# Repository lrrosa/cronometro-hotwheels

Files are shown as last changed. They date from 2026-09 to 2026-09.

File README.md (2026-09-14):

# Cronômetro Hot Wheels — 6 raias

Cronômetro de largada e chegada para pista de carrinhos com seis raias. Um
microswitch na porta de largada marca o `t0`, um sensor infravermelho
**TCRT5000** no fim de cada raia marca a chegada, e seis displays **TM1637**
mostram a colocação (1 a 6) e depois o tempo de cada carro.

Diagrama de fiação — versão Arduino

## Duas versões, mesmo comportamento

| | [`cronometro-rasp-pico`](cronometro-rasp-pico/) | [`cronometro-arduino`](cronometro-arduino/) |
| --- | --- | --- |
| Placa | Raspberry Pi Pico / RP2040 (inclusive a roxa) | Arduino UNO / Nano |
| Linguagem | C, Pico SDK 1.5.1 | C++, Arduino (um `.ino` só) |
| Tensão | 3,3 V | 5 V |
| Simulador | Wokwi no VS Code | Wokwi no VS Code **ou** wokwi.com, sem instalar nada |
| Fiação | [SVG](cronometro-rasp-pico/docs/fiacao-pico.svg) | [SVG](cronometro-arduino/docs/fiacao-arduino.svg) |
| Esquema KiCad 10 | [projeto](cronometro-rasp-pico/kicad/) · [PDF](cronometro-rasp-pico/docs/esquema-kicad.pdf) | [projeto](cronometro-arduino/kicad/) · [PDF](cronometro-arduino/docs/esquema-kicad.pdf) |
| Teto de raias | 9 | 6 |

A máquina de estados, os tempos, os sons e o formato do placar são os mesmos
nas duas. O que a plataforma obrigou a mudar está em
[diferencas-rp2040.md](cronometro-arduino/docs/diferencas-rp2040.md).

**Para só ver funcionando:** a versão Arduino no wokwi.com — dois arquivos
colados e play.

## Documentação que vale para as duas

- [Lista de material e cuidados elétricos](cronometro-rasp-pico/docs/bom.md) —
  por que o sensor é infravermelho e não LDR (a disputa mais apertada do vídeo
  de referência foi decidida por 17 ms), como montar o TCRT5000, e a conta de
  consumo.
- [Notas do projeto](cronometro-rasp-pico/NOTAS.md) — decisões, medidas e
  armadilhas, para não refazer o raciocínio depois.

## Desenhos gerados

Os diagramas de fiação e os esquemas do KiCad saem de scripts; não edite à
mão. Da raiz do repositório:

```bash
python tools/gen_esquema_svg.py
```

```bash
python tools/gen_kicad_sch.py --verificar
```

O primeiro confere, segmento a segmento, que nenhum fio de sinal cruza outro.
O segundo precisa do KiCad 10 instalado: roda o ERC e exporta o netlist pelo
próprio KiCad, conferindo rede por rede contra a pinagem do firmware — o ERC
sozinho só prova regra elétrica; é o netlist que prova que cada fio chega no
pino certo. Os dois saem com erro se a conferência falhar.

## Pacotes de release

Cada [release](https://github.com/lrrosa/cronometro-hotwheels/releases) traz
um zip por placa, com o que interessa a quem vai montar: `LEIA-ME.txt` com a
montagem em ordem, fiação em SVG e PNG, lista de material, pinagem, esquema
em PDF e o projeto KiCad, o simulador já com o binário, o código e as
licenças. O do Pico traz também quatro `.uf2` prontos — ponto decimal ×
polaridade do sensor —, para gravar sem instalar o SDK.

Os zips saem de um script, a partir de um commit limpo:

```bash
python tools/empacotar_release.py 1.0.0
```

Ele compila as quatro variantes do Pico e o sketch do Arduino, renderiza os
diagramas em PNG pelo Edge headless, troca os links que apontariam para fora
do pacote por URLs do GitHub fixadas na tag e confere que todo link relativo
que sobrou existe dentro do zip.

Precisa do Pico SDK 1.5.1, do `arduino-cli` com o core `arduino:avr` e do
Edge. No Windows, rode com um Python que **não** seja o da Microsoft Store:
os processos filhos dele não enxergam o core instalado do `arduino-cli`. O
Python que vem com o Pico SDK serve.

## Licença

Projeto com **licença dupla**, a mesma do
[RetroSC Pong](https://github.com/lrrosa/retrosc-pong) — ver [`NOTICE`](NOTICE)
para o detalhamento por arquivo:

- **Software** (firmwares, geradores em `tools/`, circuito do simulador) —
  **[GPL-3.0-or-later](LICENSE)** (`SPDX-License-Identifier: GPL-3.0-or-later`).
- **Hardware** (projetos e esquemas do KiCad, diagramas de fiação, `bom.md`,
  `pinout.md`) — **[CERN-OHL-S-2.0](LICENSE-HARDWARE.txt)**
  (`SPDX-License-Identifier: CERN-OHL-S-2.0`), a variante *Strongly
  Reciprocal* da CERN Open Hardware Licence.

As duas são **recíprocas** (copyleft): trabalhos derivados devem manter a mesma
licença e disponibilizar as fontes correspondentes — código, no caso do
software; arquivos de projeto, no caso do hardware.

Copyright (C) 2026 Leonardo Roman da Rosa.

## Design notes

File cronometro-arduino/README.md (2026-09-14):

# Cronômetro Hot Wheels — 6 pistas (Arduino UNO / Nano)

Mesmo projeto da pasta [`cronometro-rasp-pico`](../cronometro-rasp-pico/),
portado para o **ATmega328P**. Comportamento idêntico; o que muda é a
plataforma, e isso está registrado em
[docs/diferencas-rp2040.md](docs/diferencas-rp2040.md).

- Um **microswitch** na porta que solta os carrinhos marca o `t0`.
- Um **sensor infravermelho TCRT5000** no fim de cada raia marca a chegada,
  pela saída digital D0.
- Seis **displays TM1637** mostram a **colocação** (1 a 6) assim que cada
  carro cruza, e depois o **tempo** (`3721` = 3,721 s).

O código é **um arquivo só** de propósito: assim cabe num único "colar" no
wokwi.com, que compila na nuvem e não exige nada instalado.

## Desenhos

- [**Diagrama de fiação**](docs/fiacao-arduino.svg) — módulos, barramentos e cada fio com o
  nome do pino. É o que se segue na montagem.
- [**Esquema KiCad 10**](kicad/) — abra `kicad/cronometro-arduino.kicad_pro`; também
  exportado em [SVG](docs/esquema-kicad.svg) e [PDF](docs/esquema-kicad.pdf).

Diagrama de fiação

Os dois são gerados pelos scripts em `tools/`, na raiz do repositório — ver o
README de lá.

## Rodar no simulador — sem instalar nada

1. Abra **[wokwi.com](https://wokwi.com)** → *New Project* → **Arduino Uno**.
2. Na aba `sketch.ino`, apague tudo e cole o conteúdo de
   [cronometro-arduino.ino](cronometro-arduino.ino).
3. Na aba `diagram.json`, apague tudo e cole o conteúdo de
   [diagram.json](diagram.json).
4. Play. Passo a passo do que fazer dentro do simulador em
   [docs/como-simular.md](docs/como-simular.md).

> Vantagem deste caminho: não precisa compilar nada. Mas o **simulador
> local do VS Code também funciona** — ver
> [docs/como-simular.md](docs/como-simular.md).

## Compilar e gravar na placa

Pelo **Arduino IDE**: abra `cronometro-arduino.ino` — a pasta tem que se chamar
`cronometro-arduino`, como o sketch —, escolha a placa (*Arduino Uno* ou
*Arduino Nano*) e a porta, e clique em Upload.

Pelo **arduino-cli**, de dentro da pasta do sketch:

```bash
arduino-cli core install arduino:avr
arduino-cli compile -b arduino:avr:uno --warnings all --output-dir build .
arduino-cli upload -b arduino:avr:uno -p COM3 .
```

Troque `COM3` pela porta que aparece em `arduino-cli board list`. Para Nano,
use `arduino:avr:nano` (clone com bootloader antigo:
`arduino:avr:nano:cpu=atmega328old`). Com o `--output-dir build`, o
[wokwi.toml](wokwi.toml) também passa a funcionar na extensão do VS Code.

**Ocupação medida** (compilado, não estimado): programa **9252 bytes**, 28 %
dos 32 KB do UNO (29 % dos 30 KB do Nano, que tem bootloader maior);
variáveis globais **465 bytes**, 22 % da RAM. Cabe com muita folga.

## Ligações

| Função | Pino | Observação |
| --- | --- | --- |
| Sensores TCRT5000 (D0) das raias 1 a 6 | **A0 a A5** | **a ordem é obrigatória** — ver abaixo |
| Microswitch da porta | D2 | precisa ser D2 ou D3 (interrupção externa) |
| TM1637 **CLK** (comum aos seis) | D3 | |
| TM1637 DIO das raias 1 a 6 | D4, D5, D6, D7, D8, D9 | |
| Buzzer passivo (opcional) | D10 | |
| Botão TESTE / rearma (opcional) | D11 | |
| Log serial | D0/D1 (USB), 115200 | |
| Alimentação | 5 V e GND | displays e sensores |

Sobram livres só **D12 e D13**. Tabela completa, com as duas placas, em
[docs/pinout.md](docs/pinout.md).

**Por que os sensores têm que ser A0..A5, nessa ordem:** o ATmega328P só
tem **duas** interrupções externas de verdade (D2 e D3) — não dão para seis
pistas. A saída é a interrupção de *mudança de pino*: A0–A5 são a PORTC
inteira, e as seis cabem numa única `PCINT1`. A rotina lê a porta de uma vez
e descobre quem mudou pelo XOR com a leitura anterior. Isso amarra a raia
*i* ao pino A*i* — por isso não existe tabela de pinos para elas, ao
contrário dos displays.

**Tudo em 5 V**, e aqui isso é uma vantagem: o TM1637 trabalha na tensão
nativa dele (fica mais brilhante) e o DIO em 5 V não é problema nenhum,
porque o 328P é uma peça de 5 V. Na versão RP2040 isso era a armadilha mais
perigosa do projeto.

## Como se comporta

| Estado | Displays | Sai daqui quando |
| --- | --- | --- |
| **Armado** | `----` fixo (ou piscando, se a porta estiver aberta) | a porta abre |
| **Correndo** | cronômetro correndo; quem chega troca para a colocação | todos chegam, ou 8 s depois do 1º, ou 15 s no total |
| **Resultado** | alterna colocação (4,5 s) ↔ tempo (7 s) | a porta fecha (ou o botão TESTE) |

- Carro que não passa pelo sensor aparece como `dnF` e `----`.
- **Fechar a porta rearma** — não precisa de botão para a próxima prova.
- Ao ligar, cada display acende **tudo** (segmentos e pontos) e depois o
  número da própria raia:
  se um ficar apagado ou mostrar o número de outra raia, o erro está no DIO
  dele, não no código. O primeiro quadro também revela se o módulo liga um
  ponto por dígito — ver `DISPLAY_PONTO_DECIMAL`.
- **Corrida demo** (para ver o painel sem carrinho): segure o botão TESTE
  por 1 s, ou segure um carrinho sobre o sensor da raia 1 por 2 s com a prova armada.

## Ajustes

Tudo no bloco **CONFIGURAÇÃO** no topo de
[cronometro-arduino.ino](cronometro-arduino.ino):

| Constante | Para quê |
| --- | --- |
| `SENSOR_NIVEL_CARRO` | `0` (padrão) é o TCRT5000: D0 cai com o carro. `1` se o seu lote for invertido |
| `LARGADA_NIVEL_ABERTA` | idem, para o microswitch (contato NA ou NF) |
| `DISPLAY_PONTO_DECIMAL` | `0` (padrão) para o módulo de dois-pontos; `1` para o de ponto por dígito |
| `TM1637_BRILHO` | 0 a 7 — mexe direto no consumo |
| `TEMPO_MIN_MS` | piso abaixo do qual a chegada é considerada ruído |
| `ESPERA_APOS_1o_MS` | quanto esperar os retardatários depois do 1º |
| `USAR_BUZZER` / `USAR_BOTAO` | `0` libera o D10 / D11 |

`N_PISTAS` **não** é ajustável para cima aqui: seis é o teto do 328P, porque
a PORTC só expõe seis pinos no conector. Ver
[docs/diferencas-rp2040.md](docs/diferencas-rp2040.md).

## Material

O mesmo da versão RP2040 —
[lista completa e os avisos elétricos](../cronometro-rasp-pico/docs/bom.md),
inclusive por que o sensor é o TCRT5000 e não LDR, e como montá-lo.

Por causa dos 5 V, aqui **displays e sensores vão direto no 5 V** da placa, e
não é preciso o regulador 3,3 V separado que a versão RP2040 recomenda. A
conta de consumo continua valendo: por USB passa, pelo conector DC de 12 V o
regulador do UNO esquenta.

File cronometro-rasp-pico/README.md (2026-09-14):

# Cronômetro Hot Wheels — 6 pistas (RP2040)

Cronômetro de largada e chegada para pista de carrinhos com 6 raias, no
Raspberry Pi Pico / RP2040 (testado na compilação com o **Pico SDK 1.5.1**,
o mesmo do projeto Pong).

- Um **microswitch** na porta que solta os carrinhos marca o `t0`.
- Um **sensor infravermelho TCRT5000** no fim de cada raia marca a chegada daquele
  carro, pela saída digital D0. A escolha do infravermelho em vez
  do LDR está justificada com números em [docs/bom.md](docs/bom.md) — em
  resumo: a prova de referência teve colocações decididas por 17 ms, e a
  dispersão de um LDR para outro é dessa mesma ordem.
- Seis **displays TM1637** mostram a **colocação** (1 a 6) assim que cada
  carro cruza, e depois o **tempo em segundos** (`3721` = 3,721 s; se os seus
  módulos tiverem ponto por dígito, `DISPLAY_PONTO_DECIMAL = 1` mostra
  `3.721`, como no vídeo original).

Vem com um **simulador Wokwi** pronto (`diagram.json` + `wokwi.toml`) — dá
para rodar a corrida inteira no VS Code antes de comprar ou soldar nada.
Passo a passo em [docs/como-simular.md](docs/como-simular.md).

> Existe a **mesma coisa para Arduino UNO/Nano** em
> [`../cronometro-arduino`](../cronometro-arduino/), num arquivo `.ino` só,
> que roda no wokwi.com sem instalar nada. O que muda entre as duas está em
> [diferencas-rp2040.md](../cronometro-arduino/docs/diferencas-rp2040.md).

## Desenhos

- [**Diagrama de fiação**](docs/fiacao-pico.svg) — módulos, barramentos e cada fio com o
  nome do pino. É o que se segue na montagem.
- [**Esquema KiCad 10**](kicad/) — abra `kicad/cronometro-rasp-pico.kicad_pro`; também
  exportado em [SVG](docs/esquema-kicad.svg) e [PDF](docs/esquema-kicad.pdf).

Diagrama de fiação

Os dois são gerados pelos scripts em `tools/`, na raiz do repositório — ver o
README de lá.

## Como se comporta

| Estado | Displays | Sai daqui quando |
| --- | --- | --- |
| **Armado** | `----` fixo (ou piscando, se a porta estiver aberta) | a porta abre |
| **Correndo** | cronômetro correndo em cada raia; quem chega troca para a colocação | todos chegam, ou 8 s depois do 1º, ou 15 s no total |
| **Resultado** | alterna colocação (4,5 s) ↔ tempo (7 s) | a porta fecha (ou o botão TESTE) |

- Carro que não cruza o sensor aparece como `dnF` na colocação e `----` no tempo.
- Com a porta fechada, o placar fica na tela por dois ciclos inteiros
  (`RESULTADO_MIN_MS`, 23 s) antes de rearmar sozinho; com a porta aberta,
  fica até alguém fechá-la.
- **Fechar a porta rearma** — não precisa de botão para a próxima prova.
- Ao ligar, cada display acende **tudo** (segmentos e pontos) e depois o
  número da própria raia:
  se um ficar apagado ou mostrar o número de outra raia, o erro está no
  DIO dele, não no firmware. O primeiro quadro também revela se o módulo liga
  um ponto por dígito — ver `DISPLAY_PONTO_DECIMAL`.

### Corrida demo

Para ver o painel funcionando sem carrinho nenhum (no simulador ou na
bancada), há dois atalhos, e as chegadas simuladas entram pelo **mesmo
caminho** das reais:

- segurar o botão **TESTE** por 1 s (tecla `D` no Wokwi);
- ou **segurar um carrinho sobre o sensor da raia 1** por 2 s com a prova
  armada — funciona sem botão nenhum, e de quebra confere a polaridade.

## Compilar

```powershell
& "C:\Program Files\Raspberry Pi\Pico SDK v1.5.1\pico-env.ps1"
cmake -G Ninja -B build
& "C:\Program Files\Raspberry Pi\Pico SDK v1.5.1\ninja\ninja.exe" -C build
```

Saída: `build/cronometro-rasp-pico.uf2`. Para gravar, segure BOOTSEL, ligue
o USB e copie o `.uf2` para a unidade `RPI-RP2`.

`DISPLAY_PONTO_DECIMAL` e `SENSOR_NIVEL_CARRO` também podem ser escolhidos na
configuração do CMake, sem editar o `config.h` — é assim que o release gera
os quatro `.uf2` prontos:

```powershell
cmake -G Ninja -B build -DPONTO_DECIMAL=1 -DSENSOR_NIVEL=1
```

As opções ficam no cache do CMake. Para voltar ao que diz o `config.h`, passe
as duas vazias (`-DPONTO_DECIMAL= -DSENSOR_NIVEL=`) ou apague a pasta `build`.

## Ligações

Resumo — a tabela completa, com a posição física do furo em cada módulo
(Pico oficial e RP2040 roxa), está em [docs/pinout.md](docs/pinout.md).

| Função | GPIO |
| --- | --- |
| Sensores TCRT5000 (D0) das raias 1 a 6 | GP2, GP3, GP4, GP5, GP6, GP7 |
| Microswitch da porta | GP8 |
| TM1637 **CLK** (comum aos seis) | GP9 |
| TM1637 DIO das raias 1 a 6 | GP10, GP11, GP12, GP13, GP14, GP15 |
| Buzzer passivo (opcional) | GP16 |
| Botão TESTE / rearma (opcional) | GP21 |
| Log serial | USB, e UART0 em GP0/GP1 |

> **Tudo em 3,3 V — displays e sensores.** O TM1637 e o TCRT5000 têm
> pull-up para o VCC do próprio módulo: alimentados em 5 V, põem 5 V num
> GPIO do RP2040, que **não** é tolerante a 5 V. Ver [docs/bom.md](docs/bom.md),
> que também explica por que vale usar um regulador 3,3 V separado.

Os seis displays dividem o **mesmo CLK**: o TM1637 não tem endereço, quem
seleciona o chip é a linha DIO. Enquanto se escreve numa raia, os outros
cinco veem o clock mas com o DIO parado em nível alto — sem condição de
START, eles ignoram tudo. São 7 pinos em vez de 12, e trocar para um CLK
por display é só mudar a tabela em `src/config.c`.

## Arquivos

```
src/config.{h,c}    pinos, polaridades e tempos — o que se mexe
src/tm1637.{h,c}    protocolo de dois fios do display
src/display.{h,c}   fonte de 7 segmentos e formatação (tempo, colocação)
src/cronometro.{h,c} máquina de estados da prova
src/som.{h,c}       bips no buzzer (não bloqueantes)
src/main.c          init + laço principal
diagram.json        circuito do simulador Wokwi (gerado, não editado a mão)
tools/gen_diagram.py  gera o diagram.json e confere o roteamento dos fios
wokwi.toml          aponta o Wokwi para o firmware compilado
docs/               pinagem, lista de material, como simular
NOTAS.md            decisões, medidas e armadilhas do projeto
```

## Ajustes que você provavelmente vai querer mexer

Tudo em [src/config.h](src/config.h):

| Constante | Para quê |
| --- | --- |
| `N_PISTAS` | número de raias (mexa junto com as tabelas de `config.c`) |
| `SENSOR_NIVEL_CARRO` | `0` (padrão) é o TCRT5000: D0 cai com o carro. `1` se o seu lote for invertido |
| `LARGADA_NIVEL_ABERTA` | idem, para o microswitch (contato NA ou NF) |
| `DISPLAY_PONTO_DECIMAL` | `1` se o módulo tem ponto por dígito, `0` (padrão) se só tem dois-pontos no meio |
| `TM1637_BRILHO` | 0 a 7 — mexe direto no consumo, ver `docs/bom.md` |
| `TEMPO_MIN_MS` | piso de tempo abaixo do qual a chegada é considerada ruído |
| `ESPERA_APOS_1o_MS` | quanto tempo esperar os retardatários depois do 1º |

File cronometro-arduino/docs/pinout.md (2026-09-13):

# Pinagem — Arduino UNO / Nano (ATmega328P)

Aqui não existe o problema que a versão RP2040 tem com as placas clone: o
nome serigrafado na placa **é** o nome usado no código. `D4` é `D4` no UNO e
no Nano. Por isso esta página não traz tabela de posição física — traz o
mapeamento para as portas do AVR, que é o que importa para entender as
amarrações.

Os pinos ficam no bloco **CONFIGURAÇÃO** no topo de
[../cronometro-arduino.ino](../cronometro-arduino.ino).

## Sinais do projeto

| Função | Pino | Porta AVR | Dir | Observação |
| --- | --- | --- | --- | --- |
| TCRT5000 raia 1 (D0) | **A0** | PC0 | IN | ativo em 0; o pull-up já vem no módulo |
| TCRT5000 raia 2 (D0) | **A1** | PC1 | IN | |
| TCRT5000 raia 3 (D0) | **A2** | PC2 | IN | |
| TCRT5000 raia 4 (D0) | **A3** | PC3 | IN | |
| TCRT5000 raia 5 (D0) | **A4** | PC4 | IN | (é também o SDA do I²C, se um dia precisar) |
| TCRT5000 raia 6 (D0) | **A5** | PC5 | IN | (SCL) |
| Microswitch da porta | **D2** | PD2 | IN | **INT0** — contato para GND, pull-up interno |
| TM1637 **CLK** (comum) | **D3** | PD3 | OUT | vai nos seis displays |
| TM1637 DIO raia 1 | **D4** | PD4 | I/O | dreno aberto emulado |
| TM1637 DIO raia 2 | **D5** | PD5 | I/O | |
| TM1637 DIO raia 3 | **D6** | PD6 | I/O | |
| TM1637 DIO raia 4 | **D7** | PD7 | I/O | |
| TM1637 DIO raia 5 | **D8** | PB0 | I/O | |
| TM1637 DIO raia 6 | **D9** | PB1 | I/O | |
| Buzzer passivo | **D10** | PB2 | OUT | opcional (`USAR_BUZZER`) |
| Botão TESTE / rearma | **D11** | PB3 | IN | opcional (`USAR_BOTAO`) |
| Log serial | D0 / D1 | PD0/PD1 | — | 115200, pelo USB |
| **5 V** | — | — | — | displays e sensores |
| **GND** | — | — | — | massa comum |

Sobram livres **D12 (PB4)** e **D13 (PB5)**. Só.

## As três amarrações que não dá para mexer

1. **Os sensores têm que ser A0–A5, nessa ordem.** O 328P só tem duas
   interrupções externas de verdade (D2 e D3); para seis pistas a saída é a
   interrupção de mudança de pino, e A0–A5 são a PORTC inteira, que cai toda
   numa única `PCINT1`. A rotina lê `PINC` de uma vez. Trocar dois sensores
   de pino troca as raias.
2. **A largada tem que ser D2 ou D3.** São os únicos pinos com interrupção
   externa. D3 já é o CLK dos displays, então sobra D2.
3. **Seis raias é o teto.** A PORTC só expõe seis pinos no conector — PC6 é
   o RESET. O Nano tem A6/A7, mas eles são **só analógicos**: não têm
   registrador de entrada digital nem PCINT, e portanto não servem para
   sensor. Para sete ou mais raias, o caminho é outro micro (o RP2040 da
   pasta vizinha tem folga para nove).

## Armadilhas conhecidas desta pinagem

- **`tone()` usa o Timer2**, e isso desliga o `analogWrite` dos pinos **D3 e
  D11**. Aqui não dá problema porque D3 é saída digital (CLK) e D11 é
  entrada (botão) — nenhum dos dois usa PWM. Mas se um dia alguém quiser um
  LED com brilho variável, não pode ser nesses dois.
- **D10 a D13 são o barramento SPI** (SS, MOSI, MISO, SCK). O projeto usa
  D10 e D11 para buzzer e botão. Se um dia entrar um cartão SD para gravar
  os tempos, mude buzzer e botão para D12/D13 antes de ligar o SPI.
- **D13 tem o LED de bordo**, com resistor para o GND. Não serve como
  entrada com pull-up (o LED puxa o nível para baixo). Se precisar de mais
  uma entrada, use D12.
- **D0/D1 são a serial**. Ligar qualquer coisa neles atrapalha a gravação
  pelo USB e o log dos tempos.

## Cabeamento sugerido

Cada TM1637 precisa de 4 fios e cada TCRT5000 de 3 (VCC, GND e D0 — o A0
do módulo fica solto; não confundir com o **pino** A0 do Arduino, que recebe
o D0 do sensor da raia 1). Em vez de puxar tudo até a placa:

- **5 V e GND** em duas barras percorrendo o painel, com os módulos
  pendurados nelas (é assim que o `diagram.json` e o
  [diagrama de fiação](fiacao-arduino.svg) estão desenhados).
- **CLK** também em cascata, um fio curto de um display para o outro. O
  módulo preto de 0,56" tem header dos dois lados, o que deixa isso trivial.
- Só os **6 DIO** dos displays e os **6 D0** dos sensores voltam
  individualmente à placa.

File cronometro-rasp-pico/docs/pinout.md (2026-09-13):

# Pinagem

Os GPIOs ficam em [../src/config.h](../src/config.h) e
[../src/config.c](../src/config.c). O **firmware é o mesmo** para o Pico
oficial e para a RP2040 roxa — o RP2040 é idêntico, o que muda é em qual
furo da placa cada GPIO aparece.

**Posições físicas** na numeração padrão do Pico: pino 1 no canto do USB,
1–20 descem a coluna esquerda, 21–40 sobem a direita.

## Sinais do projeto

| Função | GPIO | Dir | Pico oficial | RP2040 roxa | Observação |
| --- | --- | --- | --- | --- | --- |
| TCRT5000 raia 1 (D0) | GP2 | IN | 4 | **3** | ativo em 0; o pull-up já vem no módulo |
| TCRT5000 raia 2 (D0) | GP3 | IN | 5 | **4** | |
| TCRT5000 raia 3 (D0) | GP4 | IN | 6 | **5** | |
| TCRT5000 raia 4 (D0) | GP5 | IN | 7 | **7** | |
| TCRT5000 raia 5 (D0) | GP6 | IN | 9 | **8** | |
| TCRT5000 raia 6 (D0) | GP7 | IN | 10 | **9** | |
| Microswitch da porta | GP8 | IN | 11 | **10** | contato para GND, pull-up interno |
| TM1637 **CLK** (comum) | GP9 | OUT | 12 | **11** | vai nos seis displays |
| TM1637 DIO raia 1 | GP10 | I/O | 14 | **12** | dreno aberto emulado |
| TM1637 DIO raia 2 | GP11 | I/O | 15 | **13** | |
| TM1637 DIO raia 3 | GP12 | I/O | 16 | **14** | |
| TM1637 DIO raia 4 | GP13 | I/O | 17 | **16** | |
| TM1637 DIO raia 5 | GP14 | I/O | 19 | **17** | |
| TM1637 DIO raia 6 | GP15 | I/O | 20 | **18** | |
| Buzzer passivo | GP16 | OUT | 21 | **19** | opcional (`USAR_BUZZER`) |
| Botão TESTE / rearma | GP21 | IN | 27 | **24** | opcional (`USAR_BOTAO`) |
| UART0 TX / RX (log) | GP0 / GP1 | — | 1 / 2 | 1 / 2 | opcional; o USB também loga |
| **3,3 V** | — | — | 36 | 36 | displays e sensores (ou regulador separado, ver bom.md) |
| **GND** | — | — | 3, 8, 13, 18, 23, 28, 38 | 6, 15, 35, 38 | massa comum |
| +5 V (não usado) | — | — | 40 (VBUS) | 40 (VBUS) | **não** ligue nos TM1637 |

Sobram livres: GP17 a GP20, GP22, GP26 a GP28 (os três com ADC). Dá para
crescer para 8 ou 9 raias sem reorganizar nada — só estender as tabelas de
`config.c` e `N_PISTAS`.

## Por que estes GPIOs

- **Sensores em GP2–GP7, contíguos.** Facilita conferir o cabo flat e
  permite ler as seis raias num único `gpio_get_all()`, caso um dia se
  queira amostrar por polling em vez de interrupção.
- **GP0/GP1 livres** para a UART0, que é o que o monitor serial do Wokwi lê.
- **GP16 (buzzer)** é canal A do slice 0 do PWM e não disputa nada.
- **Nada em GP23, GP24, GP25 nem GP29.** No Pico oficial esses pinos são do
  regulador, do sensor de VBUS e do LED, e nem aparecem nos furos; na roxa
  aparecem, mas usá-los amarraria o projeto a uma placa só.

## Pinagem completa das duas placas

| Pos | Pico oficial | RP2040 roxa |
| --- | --- | --- |
| 1 | GP0 | GP0 |
| 2 | GP1 | GP1 |
| 3 | GND | **GP2** |
| 4 | **GP2** | **GP3** |
| 5 | **GP3** | **GP4** |
| 6 | **GP4** | GND |
| 7 | **GP5** | **GP5** |
| 8 | GND | **GP6** |
| 9 | **GP6** | **GP7** |
| 10 | **GP7** | **GP8** |
| 11 | **GP8** | **GP9** |
| 12 | **GP9** | **GP10** |
| 13 | GND | **GP11** |
| 14 | **GP10** | **GP12** |
| 15 | **GP11** | GND |
| 16 | **GP12** | **GP13** |
| 17 | **GP13** | **GP14** |
| 18 | GND | **GP15** |
| 19 | **GP14** | **GP16** |
| 20 | **GP15** | GP17 |
| 21 | **GP16** | GP18 |
| 22 | GP17 | GP19 |
| 23 | GND | GP20 |
| 24 | GP18 | **GP21** |
| 25 | GP19 | GP22 |
| 26 | GP20 | GP23 |
| 27 | **GP21** | GP24 |
| 28 | GND | GP25 |
| 29 | GP22 | AGND |
| 30 | RUN | GP26/A0 |
| 31 | GP26/ADC0 | GP27/A1 |
| 32 | GP27/ADC1 | GP28/A2 |
| 33 | AGND | GP29/A3 |
| 34 | GP28/ADC2 | RUN |
| 35 | ADC_VREF | **GND** |
| 36 | **3V3** | **3V3** |
| 37 | 3V3_EN | 3V3_EN |
| 38 | **GND** | **GND** |
| 39 | VSYS | VIN |
| 40 | VBUS (+5 V) | VBUS (+5 V) |

Em **negrito**, as posições que o projeto usa em cada placa. Repare que a
coluna da roxa está deslocada: **confira no silk da sua placa antes de
soldar** — se o furo marcado GP16 não bater com a tabela, o módulo é da
outra variante.

## Cabeamento sugerido

Cada TM1637 precisa de 4 fios e cada TCRT5000 de 3 (VCC, GND e D0 — o A0
fica solto). Em vez de puxar tudo até o Pico:

- **3,3 V e GND** em duas barras que percorrem o painel, com os módulos
  pendurados nelas (é assim que o `diagram.json` e o
  [diagrama de fiação](fiacao-pico.svg) estão desenhados). Se usar o
  regulador 3,3 V separado recomendado em [bom.md](bom.md), é ele que
  alimenta as barras — com o GND ligado ao do Pico.
- **CLK** também em cascata, um fio curto de um display para o outro. O
  módulo preto de 0,56" tem header dos dois lados, o que deixa isso trivial.
- Só os **6 DIO** dos displays e os **6 D0** dos sensores voltam
  individualmente ao Pico.

Dá 14 fios longos em vez de 42.

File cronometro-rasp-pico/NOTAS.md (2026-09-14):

# Notas do projeto — decisões, medidas e armadilhas

Histórico do que foi decidido e por quê, para não refazer o raciocínio
depois. Escrito na primeira montagem do firmware + simulador (set/2026).

## Ponto de partida

`projeto.txt` e três capturas do vídeo original. Do vídeo saiu o
comportamento do painel, que não estava escrito em lugar nenhum:

- durante a prova os displays das raias que ainda não chegaram ficam
  ocupados (no vídeo, com todos os segmentos acesos);
- **assim que um carro cruza, aquele display passa a mostrar a colocação**,
  um dígito só, alinhado à direita;
- alguns segundos depois, todos trocam para o tempo, no formato `3.721` —
  quatro dígitos com o ponto **depois do primeiro**, o que só é possível nos
  módulos TM1637 com ponto decimal por dígito, não nos de relógio.

Aqui a raia que ainda corre mostra o **cronômetro correndo** em vez de
`8888`: é mais informativo e prova na hora que a largada pegou.

## Decisões de hardware

**Os seis TM1637 dividem o mesmo CLK.** O TM1637 não tem endereço — quem
seleciona o chip é a linha DIO, porque a transação só começa numa condição
de START (DIO descendo com CLK alto). Enquanto se escreve numa raia, os
outros cinco veem o clock com o DIO deles parado em nível alto e ignoram
tudo. Custa 7 GPIOs em vez de 12 e um fio curto entre displays vizinhos em
vez de doze fios até o Pico. `src/config.c` tem a tabela `PIN_TM_DIO[]`;
voltar para um CLK por display é mudar a estrutura em `display.c` para
guardar um `clk` diferente por raia — o driver já recebe `{clk, dio}` por
display justamente para isso.

**CLK é push-pull, DIO é dreno aberto emulado.** O CLK só é dirigido pelo
mestre, e com seis módulos pendurados (cada um com seu pull-up de 10 k) um
dreno aberto teria que puxar ~1,7 k. Já o DIO precisa ser solto para o
display dar ACK: o valor de saída fica em 0 para sempre e o que muda é a
**direção do pino** — assim nunca existe o instante entre "escrever 0" e
"virar saída" que geraria um pulso espúrio.

**Sensores em GPIOs contíguos (GP2–GP7)** — não por necessidade (a captura
é por interrupção, com carimbo de `time_us_64()`), mas porque isso deixa a
porta aberta para amostrar as seis raias num único `gpio_get_all()` se um
dia o polling for preferível, e porque facilita conferir o cabo flat.

**Nada em GP23/24/25/29.** No Pico oficial são o regulador, o sensor de VBUS
e o LED, e nem saem nos furos. Usá-los amarraria o projeto à placa roxa.

## Decisões de firmware

**A interrupção só carimba a hora.** Toda decisão fica no laço principal.
Isso é o que permite escrever nos seis displays por bit-bang (uns 4 ms por
rodada de atualização) sem perder precisão: o `time_us_64()` do carimbo já
aconteceu. A precisão do cronômetro **não depende** do período do laço.

**A primeira borda da largada é a boa.** Microswitch repica, mas o repique
vem sempre *depois* da primeira transição, nunca antes. Então não existe
janela de debounce por tempo na largada: a ISR guarda a primeira borda e
ignora as seguintes até o laço consumir. Uma janela por tempo aqui só
atrasaria o `t0` sem ganhar nada.

**As chegadas são ordenadas por tempo antes de numerar.** Duas raias podem
disparar dentro da mesma volta do laço, e nesse caso a ordem em que os
*flags* são varridos é a ordem das raias, não a ordem de chegada — numerar
direto daria a 1ª colocação para a raia de número menor. O laço recolhe
todos os eventos pendentes, ordena por carimbo e só então atribui as
colocações. É o tipo de erro que aparece uma vez em cada vinte provas e
depois nunca mais, então melhor não deixar existir. A corrida demo sorteia
tempos garantidamente **distintos** pela mesma razão: se dois pudessem
empatar em ms, o desempate cairia na ordem do laço e esconderia justamente
o erro que se quer testar.

**`TEMPO_MIN_MS` (150 ms) é o piso do que é uma chegada.** Abaixo disso é
repique do microswitch ou sombra, e a raia continua armada — o disparo é
descartado, não marcado como chegada. Vai para o log como `[ruido]`.

**A prova fecha por três caminhos:** todos chegaram, 8 s depois do primeiro
colocado, ou 15 s no total. O segundo é o que importa na prática: numa prova
com 4 carros, esperar os 15 s cheios deixaria o painel parado à toa.

**Fechar a porta rearma.** É o gesto que o operador faz de qualquer jeito
para montar a próxima prova, então não precisa de botão. O botão TESTE
existe para abortar e para a corrida demo, e é opcional (`USAR_BOTAO`).

**`REFRESH_CORRIDA_MS` = 43, e não 50.** Com 50 ms o último dígito do
milissegundo fica parado em 0 e o penúltimo só alterna 0/5 — parece display
quebrado. Com 43 os dez algarismos aparecem e a leitura fica com cara de
cronômetro de verdade. Qualquer valor não redondo serve; o que não serve é
um divisor de 10.

**Duas maneiras de rodar a corrida demo**, porque cada uma cobre um caso:
segurar o botão (rápido, é o que se usa no simulador) e **tapar o sensor da
raia 1 por 2 s** (funciona na bancada sem botão nenhum, só com a mão — e de
quebra prova que a polaridade do sensor está certa). A segunda só rearma
depois que o sensor volta ao repouso, senão um sensor com fio solto ficaria
disparando demos em série.

**As chegadas da demo entram pelo mesmo `registra_chegada()` das reais.**
Um modo demo que escrevesse direto no resultado testaria só a formatação.
Assim ele testa ordenação, colocação, som, log e ciclo de resultado — tudo
menos a borda do GPIO.

**Teste de fiação no boot:** `8888` em todos, depois o número da própria
raia em cada um. Um display apagado ou mostrando o número de outra raia
aponta o defeito no DIO daquele display, sem precisar depurar firmware. O
ACK de cada TM1637 também é conferido e vai para o log serial.

## Armadilhas de hardware anotadas antes de montar

- **TM1637 em 5 V queima o GPIO.** O DIO é bidirecional e o pull-up do
  módulo o mantém na tensão de alimentação; o RP2040 não é tolerante a 5 V.
  Tudo em 3,3 V. Detalhes em `docs/bom.md`.
- **Consumo:** seis TM1637 no brilho máximo podem passar de 200 mA, contra
  ~300 mA que o regulador do Pico entrega. Por isso `TM1637_BRILHO` = 4.
- **O LDR é o ponto fraco, e a conta que eu tinha feito estava errada.**
  Na primeira versão destas notas eu calculei a sombra a partir da largura
  do sensor (~10 mm → ~3 ms). Está errado: quem define quanto tempo o feixe
  fica tapado é o **comprimento do carro** (~68 mm), não o sensor. São
  18–36 ms conforme a velocidade — tempo bem maior do que eu supunha.
  Só que a conclusão **não melhorou**, mudou de motivo: o problema não é a
  janela ser curta demais, é o **atraso do LDR não ser igual nas seis
  raias**. Os tempos do vídeo original separam colocações vizinhas por 116,
  33, **17**, 41 e 99 ms — a disputa mais apertada foi decidida por 17 ms, e
  a diferença de resposta entre LDRs do mesmo lote é dessa mesma ordem.
  E o modo de falha é o pior possível: quanto mais rápido o carro, menor a
  janela; quem o LDR tem mais chance de perder é justamente **o mais
  rápido**. Uma falha que escolhe o vencedor é pior do que uma aleatória.
  Veredito: **barreira infravermelha** (LED IR + fototransistor atravessando
  a raia), que responde em microssegundos e cuja borda é geométrica, não
  fotométrica. Refletivo tipo TCRT5000 **não** serve para prova: o ponto de
  disparo depende da cor e da altura do carro. Detalhes e o circuito de três
  componentes em `docs/bom.md`.
  **Nada disso muda o firmware:** a chegada é borda num pino digital e
  `SENSOR_NIVEL_CARRO` cobre a polaridade. Os módulos LDR já comprados
  também não se perdem — o LM393 deles aceita um fototransistor no lugar do
  LDR.

## Sobre o simulador

`diagram.json` + `wokwi.toml`, no mesmo esquema do projeto Pong: a extensão
**Wokwi for VS Code** roda o `.elf` compilado de verdade num RP2040 emulado.
A pasta `cronometro-rasp-pico` tem que ser a **raiz do workspace**, senão os
caminhos do `wokwi.toml` não batem.

Escolhas do diagrama que não são cosméticas:

- **Chave deslizante, não botão, para a porta de largada.** A porta é um
  estado (aberta/fechada), não um toque. Com a chave, "fechar a porta"
  rearma de verdade, que é o ciclo real. O contato da direita fica **solto**
  de propósito: quem define o nível alto é o pull-up interno do RP2040,
  exatamente como no circuito real com o microswitch ligado ao GND.
- **Bounce ligado na chave.** É o que testa a regra da primeira borda.
- **Uma fileira de seis**, displays e sensores alinhados, raia 1 à esquerda,
  em vez do 3×2 do painel original — no simulador a corrida fica legível da
  esquerda para a direita.
- Alimentação e CLK em **cascata** de um módulo para o vizinho, que é como
  se cabeia de verdade e reduz de 42 para 14 os fios longos até o Pico.

### O que a primeira rodada no Wokwi ensinou

Três coisas só apareceram com o simulador aberto, e as três são sobre o
`diagram.json`, não sobre o firmware:

- **Sem waypoints, o Wokwi liga pino a pino em linha reta.** Não há
  roteamento automático. Como os pinos do TM1637 e do módulo de sensor ficam
  todos na **borda esquerda**, encadear a alimentação de um módulo para o
  vizinho desenhava uma linha reta por cima da cara do display — três riscos
  atravessando os seis dígitos. A correção é a mini-linguagem de waypoints
  (`"h-20"`, `"v120"`, com `"*"` separando o lado de origem do de destino):
  todo fio **sai para a esquerda e desce até um corredor livre** antes de
  correr na horizontal. Como os dois pinos de um encadeamento têm o mesmo
  deslocamento dentro da peça, dar o mesmo `v` nas duas pontas garante um
  traço perfeitamente horizontal por baixo dos módulos.
- **A ordem do array `parts` é a ordem de desenho, e quem vem depois fica
  por cima — inclusive capturando o clique.** Um `wokwi-text` posicionado
  em cima da chave deslizante deixou a chave **impossível de usar**. Textos
  agora ficam em regiões onde nenhuma peça e nenhum fio passam (rótulos
  acima dos displays, bloco de ajuda à direita da pista 6).
- **O layout tem que reservar corredores**, não só espaçar as peças: uma
  faixa horizontal livre entre displays e sensores, outra entre sensores e
  o Pico, e uma coluna livre entre cada par de módulos. O Pico foi parar no
  vão entre os módulos 2 e 3 para que os fios da coluna esquerda dele subam
  por essa coluna sem atravessar peça nenhuma.

Uma consequência prática do primeiro ponto: **arrastar uma peça no Wokwi
refaz o traçado**. Se um fio incomodar, mover a peça é mais rápido do que
mexer nos waypoints.

Mais duas descobertas, da segunda rodada:

- **O `wokwi-tm1637-7segment` é o módulo de relógio.** O bit 7 de um dígito
  acende os **dois-pontos centrais**, não um ponto decimal — então o tempo
  saía `37:21` em vez de `3.721`. `DISPLAY_PONTO_DECIMAL` passou a ser `0`
  por padrão: quatro dígitos limpos, `3721`, que se lê 3,721 s. Só que isso
  criou uma ambiguidade — sem separador, `1234` tanto pode ser 1,234 s como
  12,34 s. A saída foi dar um *significado* ao separador: **acima de 10 s ele
  acende nos dois tipos de módulo**. Aceso quer dizer "formato SS.mm",
  apagado quer dizer "formato S.mmm". No módulo de ponto sai `12.34`, no de
  relógio `12:34`, e os dois se leem igual.
- **O Wokwi não tem fototransistor nem barreira óptica.** Tem LDR e tem
  receptor IR de 38 kHz — e o de 38 kHz não serve para barreira, porque tem
  AGC e espera rajadas, não feixe contínuo. A barreira virou então **o que o
  GPIO realmente enxerga**: pull-up de 10 kΩ para 3V3 e uma chave para o GND,
  com a `wokwi-slide-switch` fazendo o papel do fototransistor (esquerda =
  conduzindo = feixe passando = 0; direita = aberto = carro cortou = 1).
  Ficou mais honesto que o módulo LDR *e* mais rápido de usar: um clique por
  chegada, e o estado de cada raia fica visível. Os LEDs IR não entram no
  diagrama de propósito — são um ramo sempre aceso que nunca toca o Pico.

### Som

O buzzer do Wokwi é onda quadrada, e agudo curto some. A largada virou um
tom **grave e longo** (330 Hz, 600 ms — cara de buzina de largada), a
chegada um bip curto que **desce 150 Hz por colocação** (dá para ouvir quem
chegou em que lugar sem olhar), e o fim da prova um 220 Hz de 450 ms. Tudo
em `config.h`, na seção de sons.

### Tempo de placar

Colocação 4,5 s e tempo 7 s, alternando. Com a porta **aberta** o placar
fica lá até alguém fechá-la — é o caso real, o operador lê com calma. O
rearme automático (`RESULTADO_MIN_MS`, 23 s = dois ciclos inteiros) só vale
quando a porta já está fechada, que é o caso da corrida demo.

O que o simulador cobre e o que não cobre está em `docs/como-simular.md`.
Resumo do que **não** cobre: velocidade do sensor, consumo e ruído de cabo.

## O port para Arduino

Feito depois que a versão RP2040 estava pronta, e de propósito **sem**
reescrever a lógica: mesma máquina de estados, mesmos tempos, mesmos nomes
de função em camelCase. O detalhamento está em
`../cronometro-arduino/docs/diferencas-rp2040.md`; aqui ficam só as três
coisas que mudaram alguma **decisão**, não só a sintaxe.

- **O ATmega328P só tem duas interrupções externas** (D2 e D3) — não dão
  para seis pistas. A saída foi a interrupção de *mudança de pino*: as seis
  barreiras foram para **A0–A5**, que são a PORTC inteira e caem todas numa
  única `PCINT1`; a rotina lê `PINC` de uma vez e descobre quem mudou pelo
  XOR com a leitura anterior. Isso **amarra a raia *i* ao pino A*i***, e
  fixa o teto do projeto em **seis raias** nessa placa: a PORTC só expõe
  seis pinos no conector, e o A6/A7 do Nano é só analógico, sem PCINT.
- **Os 5 V do AVR resolvem de graça a armadilha mais perigosa do RP2040.**
  Lá, alimentar o TM1637 em 5 V colocaria 5 V no DIO, por causa do pull-up
  do módulo, direto num pino que não tolera isso. No Arduino o display vai
  na tensão nativa dele e ainda fica mais brilhante. A única mudança de
  material é o resistor do LED IR: 330 Ω em 5 V no lugar de 220 Ω.
- **`micros()` tem 32 bits e estoura em 71,6 minutos.** Toda conta de tempo
  virou subtração sem sinal (`agora - t0`), que atravessa o estouro
  corretamente — em lugar nenhum existe `agora > t0 + X`. Escrever isso
  expôs um detalhe que estava **errado também no RP2040**: em `tick_armado`
  a bandeira da largada era baixada *antes* de o carimbo ser lido, e um
  repique da porta nesse intervalo podia trocar `largada_us` debaixo da
  leitura. Agora as duas versões leem o carimbo primeiro. É o mesmo cuidado
  que o laço já tinha com os sensores, que eu não tinha aplicado aqui.

Sobre ferramentas: o código Arduino está num arquivo `.ino` só porque o
caminho mais curto para ver a coisa rodando é colá-lo no **wokwi.com**, que
compila na nuvem. Antes de o `arduino-cli` existir nesta máquina, o sketch
foi verificado com `arm-none-eabi-g++ -fsyntax-only -Wall -Wextra` contra um
stub da API do Arduino — vale registrar que isso **funcionou**: quando o
avr-gcc finalmente compilou o sketch com `--warnings all`, não apareceu
nenhum aviso novo (os únicos que saíram são do `new.cpp` do próprio core do
Arduino). É um truque reaproveitável quando falta o compilador certo: pega
todo erro de C++ e de tipo, só não pega o que é específico do alvo.

Hoje o `arduino-cli` 1.5.2 está instalado em `C:\Users\Leonardo\arduino-cli`
com o core `arduino:avr`, e a compilação de verdade mede: **9202 bytes de
programa (28 % do UNO, 29 % do Nano) e 465 bytes de RAM (22 %)**. Isso
também destravou o **simulador local** para a versão Arduino: a extensão
Wokwi do VS Code nunca compilou nada — ela carrega um binário pronto, e o
`.hex` do avr-gcc serve tão bem quanto o `.uf2` do Pico SDK. O que faltava
era quem produzisse o `.hex`.

## TCRT5000, desenhos e preparação para o GitHub (set/2026)

**O sensor virou TCRT5000**, por decisão de projeto: é o módulo à mão. O
raciocínio contra o LDR continua valendo (a disputa mais apertada do vídeo foi
decidida por 17 ms), e o TCRT5000 é infravermelho de verdade — fototransistor
e LM393, resposta em microssegundos. A ressalva que eu tinha anotado contra
ele ("é refletivo, depende do carro") não sumiu: virou **instrução de
montagem**. Por baixo da pista, olhando para cima, com o fundo do carro a
2–5 mm, e os seis trimpots ajustados com o mesmo carro. Se algum carro teimar,
aquele ponto vira barreira sem mexer no firmware — só a polaridade.

Três coisas saíram das fotos dos módulos, e não de datasheet:

- **O D0 do TCRT5000 cai para 0 com o carro** (coletor aberto do LM393, com
  pull-up no módulo). `SENSOR_NIVEL_CARRO` virou `0` nas duas versões. No
  Wokwi, a peça de luz tem o mesmo header (VCC/GND/DO/AO) e a mesma lógica —
  escuro = sem carro = 1 —, então o diagrama voltou a usá-la, com `lux` em 0.
- **O pull-up do D0 vai para o VCC do módulo.** É a armadilha do TM1637 de
  novo: no RP2040, sensor alimentado em 5 V põe 5 V num GPIO que não tolera.
  Na versão Pico, displays **e** sensores vão em 3,3 V.
- **O resistor do LED IR é o `181` (180 Ω), e esse LED nunca apaga**: ~13 mA
  por módulo em 3,3 V, ~24 mA em 5 V. Somado aos displays, o 3V3 do Pico
  chega a 200–260 mA, perto do que a Raspberry recomenda para esse pino. Daí a
  recomendação de um regulador 3,3 V separado na versão RP2040.

E uma do display: o módulo preto de 0,56" tem um ponto embaixo de cada dígito
**no vidro**, mas isso não garante que o ponto esteja ligado ao TM1637. Não dá
para saber olhando, então o teste de fiação do boot passou a acender `0xFF` —
todos os segmentos e todos os pontos —, e o primeiro quadro diz qual valor de
`DISPLAY_PONTO_DECIMAL` usar.

### Os diagramas de fiação (SVG)

O pedido era "como no simulador, mas mais fácil de entender". O simulador
desenha 48 fios porque cada módulo puxa a própria alimentação até a placa; o
diagrama troca isso por **barramentos** de V+, GND e CLK com derivações
curtas. Sobram ~18 fios desenhados — que é também como se cabeia de verdade.

Olhar o render achou três defeitos que o código não mostrava: o barramento de
CLK começava no pino da placa e deixava a derivação do display 1 **solta no
ar** (o display 1 fica à esquerda do pino); os rótulos dos pinos ficavam logo
abaixo do pad e eram **atravessados pela própria derivação**; e as notas do
rodapé vazavam da caixa. Vale para qualquer desenho gerado: ler o código não
substitui olhar a imagem.

Depois, olhando o desenho pronto, apareceram **fios de sinal passando uns por
cima dos outros**: D4/D5 e A4/A5 no Arduino, GP10/GP11 e GP6/GP7 no Pico, e
ainda o fio do display 1 cortando a descida do CLK. A causa é geométrica.
Cada fio é um "Z" — desce do módulo, anda numa faixa, desce no pino — e dois
Zs se cruzam quando o trecho horizontal de um contém o pad ou o pino do
outro. A correção não foi trocar a ordem das faixas: foi escolher os pinos da
placa de modo que os trechos horizontais fiquem **disjuntos**, o que elimina
o cruzamento em qualquer ordem, e tirar o CLK da borda de cima da placa. Como
"parece certo" já tinha falhado uma vez, o gerador agora **confere** segmento
a segmento e sai com erro se achar cruzamento — e antes se autotesta contra o
caso D4/D5 antigo, para o "nenhum cruzamento" dele valer alguma coisa. O único
cruzamento entre fios que não dá para evitar (o 3V3 da placa passando pela
coluna de GND) ganhou uma ponte em arco.

### Os esquemas do KiCad

Gerados por `tools/gen_kicad_sch.py`, que **lê os símbolos da biblioteca do
KiCad instalado** — posição e número de cada pino — em vez de copiá-los.
Ligações por rótulo de rede, alimentação por símbolo de power (rotacionado na
ponta de cada toco, porque os pinos de um header ficam a 2,54 mm e símbolos em
pé se sobreporiam), no-connect em todo pino livre. Duas decisões foram impostas
pelo ERC:

- **Arduino:** os três GND do símbolo do UNO são `power_in` e nada "dirige" a
  rede — ela leva um `PWR_FLAG`.
- **Pico:** o AGND fica sem ligação. Ele e o GND são `power_out` no símbolo, e
  uni-los é erro de ERC; como o ADC não é usado, não faz falta.

**ERC limpo não prova que o esquema está certo** — prova que não há pino solto
nem alimentação sem fonte. Um rótulo `DIO_3` no pino errado passa no ERC. Por
isso o `--verificar` exporta o **netlist** pelo próprio KiCad e confere rede
por rede contra a pinagem do firmware. Os dois esquemas saíram com ERC 0/0 e o
netlist conferindo em todas as redes.

O ERC também não vê **texto encavalado**, e dois casos só apareceram no render
(o painel do navegador não abria o SVG exportado, de 1,2 MB; o Edge do Windows
em modo headless renderizou recortes em PNG sem instalar nada):

- **O KiCad compõe o ângulo de um campo com a rotação do símbolo**, e quando a
  soma dá 180° desenha na horizontal mas **inverte a justificação**. Com o
  campo a 0°, o "GND" de um símbolo girado saía vertical; com o campo a 90°,
  saía horizontal mas em cima do próprio desenho — só nos símbolos girados
  90°, não nos de 270°, e foi essa assimetria que denunciou a regra. O certo é
  girar o campo por −rotação: a soma zera e nada é invertido.
- **Rótulo de rede fica acima do fio**, não centrado nele. Nos TCRT5000 o
  `SENSOR_n` do pino 3 subia até encostar no "GND" do pino 2, logo acima; o
  toco do rótulo ficou mais comprido para desencontrar os dois na horizontal.

### Repositório

A pasta do Pico virou `cronometro-rasp-pico`, e o alvo do CMake mudou junto,
para o `.uf2` ter o nome da pasta. O repositório se chama
`cronometro-hotwheels`, com licença GPL-3.0-or-later. Ficam **fora** dele,
pelo `.gitignore` da raiz, as fotos de anúncio em `módulos/` e as capturas do
vídeo original — são de terceiros. O `projeto.txt`, as notas iniciais com os links do
anúncio e do vídeo, também fica fora.

**Licença dupla, a mesma do Pong:** software (firmwares, geradores, circuito do
simulador) em GPL-3.0-or-later; hardware (KiCad, diagramas de fiação, `bom.md`,
`pinout.md`) em CERN-OHL-S-2.0, com o texto em `LICENSE-HARDWARE.txt` e o
detalhamento por arquivo em `NOTICE`. A fronteira que vale lembrar: o script
que gera um desenho é software, mas o desenho que ele produz é hardware — por
isso os SVGs levam `SPDX-License-Identifier: CERN-OHL-S-2.0` e o carimbo dos
esquemas repete a linha de licença dos esquemas do Pong.

## Release v1.0.0 (set/2026)

**O carimbo do KiCad estourou a moldura.** As linhas de comentário do
carimbo (`comment 1..4`) não quebram nem encolhem: o formato de folha padrão
tem 108 mm de largura útil e texto de 1,5 mm, e as primeiras linhas, de 88 e
99 caracteres, passaram da borda direita da folha. ERC e netlist não veem
isso; só o render. Hoje cada linha tem no máximo 62 caracteres (cabem uns
70) e o gerador recusa texto maior antes de gravar.

**Um zip por placa**, montado por `tools/empacotar_release.py` a partir de
um commit limpo. As decisões:

- **Quatro `.uf2` prontos no Pico**, um para cada combinação de
  `DISPLAY_PONTO_DECIMAL` e `SENSOR_NIVEL_CARRO`: são as duas coisas que só
  se descobrem com o hardware na mão, e quem monta não quer instalar o SDK
  por causa delas. Para compilar as variantes sem editar o `config.h`, os
  dois `#define` ganharam `#ifndef` e o CMake ganhou `-DPONTO_DECIMAL` e
  `-DSENSOR_NIVEL`. O script para se duas variantes derem o mesmo binário —
  seria sinal de que a opção não chegou ao compilador. Conferido à mão
  também: sem opção nenhuma o `.uf2` sai idêntico, byte a byte, ao compilado
  com `0`/`0`.
- **No Arduino, só o `.ino`**: quem monta tem o IDE, e as duas opções são uma
  linha no topo do arquivo. O zip abre numa pasta `cronometro-arduino` porque
  o IDE só abre um sketch dentro de pasta de mesmo nome.
- **`build/` vai junto**, com o binário padrão no caminho que o `wokwi.toml`
  espera: o simulador do VS Code roda direto do zip, sem compilar nada.
- **Diagrama de fiação também em PNG** (2×): nem todo visualizador abre SVG,
  e é o arquivo que se leva para a bancada.
- **Links:** cada zip mantém a estrutura da pasta da placa, então os links
  relativos continuam valendo. O que apontaria para fora (a outra placa, as
  notas, os geradores) vira URL do GitHub fixada na tag, e o script falha se
  sobrar link relativo para arquivo que não está no zip. A `bom.md`, que mora
  na pasta do Pico, vai copiada para o zip do Arduino.
- **Caminhos desta máquina** saíram dos documentos do Arduino (onde o
  `arduino-cli` está instalado aqui): valiam para esta bancada, não para quem
  baixa o projeto.
- **O script não roda com o Python da Microsoft Store.** Esse Python roda
  empacotado, e os processos filhos dele enxergam uma cópia privada do
  `AppData`: o `arduino-cli` chamado pelo script não via o core `arduino:avr`
  instalado em `Arduino15`, saía baixando índices para uma pasta vazia e
  falhava. O Python que vem com o Pico SDK é comum e serve. O script confere o
  core antes de compilar e explica isso quando falta. Outra do mesmo tipo: o
  `msedge.exe` headless volta na hora e o PNG só aparece depois, então o script
  espera o arquivo parar de crescer e confere a dimensão no cabeçalho do PNG.

## Estado atual

- **RP2040:** compila limpo no Pico SDK 1.5.1 (`build/cronometro-rasp-pico.uf2`).
- **Arduino:** compila limpo no `arduino-cli` 1.5.2 — 9252 bytes de programa
  (28 %) e 465 bytes de RAM (22 %).
- **Simuladores:** Wokwi das duas versões, com o TCRT5000 modelado pela peça de
  luz. As duas rodaram no VS Code antes da troca de sensor.
- **Desenhos:** diagramas de fiação em SVG e esquemas do KiCad 10 das duas
  placas, com ERC 0/0 e netlist conferido.
- **Publicado** em https://github.com/lrrosa/cronometro-hotwheels, com o
  release v1.0.0: um zip por placa.
- Nada montado em hardware.

## Próximos passos prováveis

1. Um TCRT5000 por baixo de uma raia: achar a distância e o ponto do trimpot
   que disparam com **todos** os carros da coleção e não disparam com a raia
   vazia.
2. Ligar um display e olhar o primeiro quadro do boot: ponto por dígito
   (`DISPLAY_PONTO_DECIMAL = 1`) ou só dois-pontos (`0`).
3. Na versão RP2040, medir a corrente do 3V3 com tudo aceso e decidir pelo
   regulador separado.
4. Mesmo carro, cinco descidas na mesma raia, e olhar a dispersão no log
   serial. Depois trocar os sensores de raia, para separar viés de sensor de
   atrito de raia.
5. Só então o painel e a fiação definitiva.

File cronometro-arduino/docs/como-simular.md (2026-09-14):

# Como rodar no simulador — versão Arduino

Dois caminhos. O primeiro não exige instalar nada.

## Caminho 1 — wokwi.com (recomendado)

O Wokwi compila o sketch na nuvem; a sua máquina só precisa do navegador.

1. [wokwi.com](https://wokwi.com) → **New Project** → **Arduino Uno**.
2. Aba `sketch.ino`: apague tudo, cole
   [../cronometro-arduino.ino](../cronometro-arduino.ino).
3. Aba `diagram.json`: apague tudo, cole [../diagram.json](../diagram.json).
4. **Play** (▶). A primeira compilação demora uns segundos.

Salve o projeto na sua conta para não perder — e guarde o link, porque é
mais rápido reabrir do que colar de novo.

## Caminho 2 — simulador local, na extensão do VS Code

Funciona igual à versão RP2040, e pelo mesmo motivo: **a extensão Wokwi não
compila nada — ela só carrega um binário já pronto** num microcontrolador
emulado. Para o RP2040 esse binário é o `.uf2` do Pico SDK; para o Arduino é
o `.hex` do avr-gcc. O que faltava aqui era quem produzisse o `.hex`, e é
isso que o `arduino-cli` resolve. O `wokwi.toml` é só o bilhete dizendo onde
o binário está.

É preciso o `arduino-cli` com o core AVR instalado
(`arduino-cli core install arduino:avr`). Então:

1. Compile, de dentro da pasta `cronometro-arduino`:

```bash
arduino-cli compile -b arduino:avr:uno --warnings all --output-dir build .
```

> Veio do zip do release? A pasta `build/` já traz o `.hex` compilado:
> dá para pular este passo enquanto não mexer no código.

2. Abra **a pasta `cronometro-arduino` como raiz do workspace** do VS Code
   (não a pasta de cima — os caminhos do `wokwi.toml` são relativos à raiz).
3. Abra `diagram.json` e rode `Ctrl+Shift+P` → **Wokwi: Start Simulator**.

O `--output-dir build` é o que faz o `.hex` e o `.elf` caírem onde o
[wokwi.toml](../wokwi.toml) espera. Mudou o sketch? Recompile e reinicie o
simulador.

Com o `.elf` presente a extensão também dá **depuração**: pontos de parada e
inspeção de variáveis dentro do VS Code, o que o wokwi.com não oferece.

### Qual dos dois usar

| | wokwi.com | VS Code |
| --- | --- | --- |
| Compilar antes | não | sim |
| Editar o sketch | no navegador | no seu editor, com git |
| Depurador | não | sim (precisa do `.elf`) |
| Bom para | ver funcionando, mostrar para alguém | trabalhar no código |

## O que fazer dentro do simulador

Assim que liga, os seis displays acendem tudo (segmentos e pontos), depois o número da raia, e
param em `----`: é o teste de fiação.

| Quero | Faço |
| --- | --- |
| **Ver uma corrida inteira** | aperte a tecla `D` e **segure 1 segundo** |
| Largar a prova | clique na **metade direita** da chavinha PORTA DE LARGADA |
| Passar um carrinho na raia N | clique no sensor TCRT5000 da raia N e **suba a luz** |
| Rearmar para a próxima | PORTA para a **esquerda** e sensores de volta ao escuro (ou toque `D`) |
| Ver os tempos em texto | aba **Serial Monitor**, 115200 |

### O caminho realista

1. Chavinha PORTA à esquerda (porta fechada). Displays em `----`.
2. Clique na **metade direita** da PORTA — é a porta abrindo. Sai o tom
   grave da largada e os seis displays começam a contar. (As chavinhas do
   Wokwi viram ao receber o clique do lado para onde você quer levá-las;
   não precisa arrastar.)
3. Clique num sensor e **suba a luz** no controle que aparece — é o
   carrinho passando por cima e refletindo o infravermelho. Aquele display
   congela e passa a mostrar a colocação. (O Wokwi não tem TCRT5000; a peça
   de luz usada tem o mesmo header e a mesma lógica: escuro = sem carro,
   D0 em 1; claro = carro, D0 em 0.)
4. Repita nas outras raias, na ordem que quiser. A ordem dos cliques é a
   ordem de chegada.
5. Quem ficar no escuro vira `dnF`. A prova fecha sozinha 8 s depois do
   primeiro colocado.
6. No resultado, os displays alternam colocação (4,5 s) e tempo (7 s), e
   ficam assim enquanto a porta estiver aberta.
7. Clique na metade esquerda da PORTA: rearmado.

> Subir seis controles de luz na velocidade certa é chato — por isso existe a corrida
> demo (tecla `D` segurada). Ela sorteia seis tempos entre 2,4 e 4,6 s e
> **entra pelo mesmo caminho das chegadas reais**, então serve para conferir
> ordenação, formatação e o ciclo de resultado. O que ela *não* testa é a
> borda vinda do pino — para isso, suba a luz de um sensor à mão em pelo
> menos uma raia.

## O que dá para conferir aqui

- a colocação sai na ordem certa, inclusive com duas raias quase juntas;
- o tempo sai como `3721`, que se lê 3,721 s (o TM1637 do Wokwi é o de
  relógio, só com dois-pontos no meio — e o módulo azul do pacote de 10
  também é, por isso `DISPLAY_PONTO_DECIMAL` está em `0`);
- **a interrupção de mudança de pino** funciona com os seis sensores: se a
  `PCINT1` estivesse mal configurada, alguma raia simplesmente não
  registraria;
- os seis TM1637 funcionam com o **CLK compartilhado** — se houvesse
  conflito, displays vizinhos mostrariam lixo quando um deles é escrito;
- o repique do microswitch não antecipa nem duplica a largada (a chavinha
  do Wokwi tem bounce ligado de propósito);
- o rearme pela porta e o `dnF` de quem não chegou;
- o log serial completo de cada prova.

## O que **não** dá (só na bancada)

- a distância e o trimpot de cada TCRT5000 com os carros de verdade — é o
  ajuste físico que resta, ver
  [a lista de material](../../cronometro-rasp-pico/docs/bom.md);
- consumo dos seis displays a 5 V (por USB dá; pelo conector DC de 12 V o
  regulador esquenta — ver [diferencas-rp2040.md](diferencas-rp2040.md));
- ruído elétrico no cabo dos sensores.

## Se mexer no diagrama

`diagram.json` é **gerado**, não editado à mão:

```bash
python tools/gen_diagram.py
```

O script calcula os waypoints de cada fio (sem eles o Wokwi liga pino a pino
em linha reta, e a fiação passa por cima dos dígitos), confere se alguma
peça ou texto invade as faixas reservadas para fiação, e ainda confere se os
pinos do diagrama batem com os do sketch.

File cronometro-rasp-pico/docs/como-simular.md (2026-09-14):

# Como rodar no simulador Wokwi

O simulador roda o **firmware compilado de verdade** dentro de um RP2040
emulado — é o mesmo `.elf` que vai para a placa. Se funcionar aqui, o que
sobra para dar errado na bancada é fiação e sensor, não lógica.

## Uma vez só

1. No VS Code, instale a extensão **Wokwi for VS Code** e faça login
   (é gratuito; o login abre o navegador e grava o token em `~/.wokwi/`).
2. Abra **a pasta `cronometro-rasp-pico`** como raiz do workspace —
   não a pasta de cima. Os caminhos do `wokwi.toml` são relativos à raiz,
   e com a pasta errada o simulador reclama que não acha o firmware.

## Toda vez

1. Compile:

```powershell
& "C:\Program Files\Raspberry Pi\Pico SDK v1.5.1\pico-env.ps1"
& "C:\Program Files\Raspberry Pi\Pico SDK v1.5.1\ninja\ninja.exe" -C build
```

> Veio do zip do release? A pasta `build/` já traz o firmware padrão
> compilado: dá para pular este passo enquanto não mexer no código.

2. Abra `diagram.json`.
3. `Ctrl+Shift+P` → **Wokwi: Start Simulator**.

Mudou o código? Recompile e reinicie o simulador — ele relê o `.uf2`.

## O que fazer dentro do simulador

Assim que liga, os seis displays acendem tudo (segmentos e pontos), depois o número da raia,
e param em `----`: é o teste de fiação.

| Quero | Faço |
| --- | --- |
| **Ver uma corrida inteira** | aperte a tecla `D` e **segure 1 segundo** |
| Largar a prova | clique na **metade direita** da chavinha PORTA DE LARGADA |
| Passar um carrinho na raia N | clique no sensor TCRT5000 da raia N e **suba a luz** |
| Rearmar para a próxima | PORTA para a **esquerda** e sensores de volta ao escuro (ou toque `D`) |
| Ver os tempos em texto | aba **Serial Monitor** do simulador |

### O caminho realista

1. Chavinha à esquerda (porta fechada). Os displays mostram `----`.
2. Clique na **metade direita** da chavinha — é a porta abrindo. Sai o tom
   grave da largada e os seis displays começam a contar. (A chavinha é uma
   `wokwi-slide-switch`: ela vira ao receber o clique do lado para onde você
   quer levá-la; não precisa arrastar.)
3. Clique num sensor e **suba a luz** no controle que aparece — é o
   carrinho passando por cima e refletindo o infravermelho. Aquele display
   congela e passa a mostrar a colocação. (O Wokwi não tem TCRT5000; a peça
   de luz usada tem o mesmo header e a mesma lógica: escuro = sem carro,
   D0 em 1; claro = carro, D0 em 0.)
4. Repita nas outras raias, na ordem que quiser. A ordem dos cliques é a
   ordem de chegada.
5. Quem ficar no escuro vira `dnF`. A prova fecha sozinha 8 s depois do
   primeiro colocado.
6. No resultado, os displays alternam colocação (4,5 s) e tempo (7 s), e
   ficam assim enquanto a porta estiver aberta.
7. Clique na metade esquerda da chavinha: rearmado.

> Subir seis controles de luz na velocidade certa é chato — por isso existe a
> corrida demo (tecla `D` segurada). Ela sorteia seis tempos entre 2,4 e
> 4,6 s e **entra pelo mesmo caminho das chegadas reais**, então serve para
> conferir ordenação, formatação e o ciclo de resultado. O que ela *não*
> testa é a borda vinda do sensor — para isso, use o arraste manual em pelo
> menos uma raia.

## O que dá para conferir no simulador (e o que não dá)

**Dá:**

- a colocação sai na ordem certa, inclusive com duas raias chegando quase juntas;
- o tempo aparece no formato certo — `3721`, que se lê 3,721 s (o TM1637 do
  Wokwi é o de relógio, só com dois-pontos no meio, então o padrão é não
  acender separador nenhum abaixo de 10 s);
- os seis TM1637 funcionam com o **CLK compartilhado** — se houvesse conflito,
  displays vizinhos mostrariam lixo quando um deles é escrito;
- o repique do microswitch não antecipa nem duplica a largada (a chavinha do
  Wokwi tem bounce ligado de propósito);
- o rearme pela porta e o `dnF` de quem não chegou;
- a fiação: cada fio sai pela esquerda do módulo e desce até um corredor
  livre antes de correr na horizontal, então nada passa por cima dos
  dígitos. Se ainda assim algum fio incomodar, **arraste a peça** — o Wokwi
  refaz o traçado sozinho;
- o log serial completo de cada prova.

**Não dá** (só na bancada):

- a distância e o trimpot de cada TCRT5000 com os carros de verdade — é o
  ajuste físico que resta, ver [bom.md](bom.md);
- consumo dos seis displays no regulador de 3,3 V do Pico;
- ruído elétrico no cabo dos sensores.

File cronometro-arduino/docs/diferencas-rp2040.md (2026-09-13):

# O que muda do RP2040 para o ATmega328P

As duas versões fazem a mesma coisa e têm a mesma máquina de estados. Este
arquivo registra só onde a plataforma obrigou a mudar alguma coisa — para
quando um dia for preciso mexer numa e lembrar de mexer na outra.

## 1. Interrupções — a diferença que teve consequência de projeto

| | RP2040 | ATmega328P |
| --- | --- | --- |
| Interrupção por borda | em **qualquer** GPIO, com callback por pino | só **D2 (INT0)** e **D3 (INT1)** |
| Saída para os 6 sensores | um `gpio_set_irq_enabled` por pino | **PCINT** — interrupção de *mudança de pino* |

No AVR, os sensores foram para **A0–A5**, que são a PORTC inteira e caem
todas na `PCINT1`. A rotina lê `PINC` de uma vez e descobre quem mudou pelo
XOR com a leitura anterior:

```c
ISR(PCINT1_vect) {
    const unsigned long agora = micros();
    const uint8_t atual = PINC & 0x3F;
    const uint8_t mudou = atual ^ pincAnt;
    pincAnt = atual;
    ...
}
```

Três consequências:

- **A raia *i* tem que estar em A*i*.** Não existe tabela de pinos para os
  sensores, ao contrário dos displays. Trocar duas de lugar troca as raias.
- **Seis é o teto.** A PORTC só expõe seis pinos no conector (PC6 é o
  RESET). No Nano existem A6/A7, mas eles são **só analógicos**: não têm
  registrador de entrada digital nem PCINT. Na versão RP2040 sobravam pinos
  para oito ou nove raias; aqui, não.
- **Dois sensores que disparem dentro da mesma interrupção recebem o mesmo
  carimbo** e o desempate cai na ordem das raias. Na prática isso exige uma
  diferença menor que o tempo de uma ISR (~5 µs) — uns 15 µm de pista.

A largada ficou em **D2 (INT0)**, com interrupção só dela, porque é a borda
mais importante do sistema.

## 2. Relógio

| | RP2040 | ATmega328P |
| --- | --- | --- |
| Função | `time_us_64()` | `micros()` |
| Largura | 64 bits (não estoura nunca) | **32 bits, estoura em 71,6 min** |
| Resolução | 1 µs | **4 µs** (prescaler /64 do Timer0) |

4 µs é 250 vezes mais fino que o milissegundo que a prova precisa, então a
resolução não é problema. O estouro é: **toda conta de tempo é subtração sem
sinal** (`agora - t0`), que atravessa o estouro corretamente. Em nenhum
lugar existe `agora > t0 + X`, que quebraria. O `somTick()` compara
`(long)(millis() - somFimMs) < 0` pelo mesmo motivo.

`micros()` **pode** ser chamada dentro de uma ISR no AVR: a implementação do
core trata o estouro pendente do Timer0 antes de montar o valor.

## 3. Tensão — aqui o AVR é melhor

O 328P é uma peça de **5 V**, e o TM1637 também. Some a armadilha mais
perigosa da versão RP2040: lá, alimentar o display em 5 V colocaria 5 V no
DIO (pelo pull-up do módulo) direto num pino que **não é tolerante a 5 V**.

O mesmo vale para o TCRT5000, cujo D0 tem pull-up para o VCC do módulo:
aqui ele vai em 5 V sem risco. E os dois ganham com isso — os dígitos ficam
mais brilhantes, e o LED IR do sensor recebe quase o dobro de corrente (o
resistor dele é o mesmo), o que dá mais alcance.

**Consumo:** seis TM1637 a 5 V no brilho 4 dão uns 120–180 mA, e os seis
TCRT5000 mais ~145 mA (o LED IR nunca apaga). Com a placa, 300–380 mA. O
UNO por **USB** aguenta (o polifusível é de 500 mA). Pelo **conector DC de
12 V**, não: o regulador dissiparia mais de 2 W. Alimente por USB ou ponha
5 V direto no pino 5 V.

## 4. Velocidade

16 MHz contra 125 MHz, e no Arduino `digitalWrite`/`pinMode` custam alguns
microssegundos cada (contra alguns nanossegundos do acesso direto ao
registrador). O bit-bang dos TM1637 ficou em ~1,2 ms por display, ~7 ms para
os seis, contra ~4 ms no RP2040.

Não muda nada de importante: com `REFRESH_CORRIDA_MS` em 43, isso é ~17 % do
tempo, e **a precisão do cronômetro não depende do laço** — quem carimba a
hora é a interrupção. Se um dia incomodar, o caminho é acesso direto a
registrador no lugar de `digitalWrite`, não baixar o `TM1637_BIT_US`.

## 5. Memória

2 KB de RAM contra 264 KB. Duas consequências no estilo do código:

- todo texto de log vai em `F("...")`, que o deixa na flash;
- os tempos da corrida demo são `uint16_t` em vez de `uint32_t`.

O sketch usa bem menos que os 2 KB, mas o hábito do `F()` é o que evita a
surpresa de a RAM acabar em silêncio quando alguém acrescentar mensagens.

## 6. Aleatoriedade

Na versão RP2040, `get_rand_32()` do SDK. No AVR, `random()` precisa de
semente, e o truque clássico — `randomSeed(analogRead(A0))` — **não serve
aqui**, porque A0–A5 estão todos ocupados pelas barreiras e nenhum está
solto para captar ruído.

A semente é `micros()` no instante em que a pessoa dispara a primeira
corrida demo. É um gesto humano: a variação natural entre execuções é de
milhares de microssegundos, muito mais do que a demo precisa.

## 7. Ferramentas

| | RP2040 | Arduino |
| --- | --- | --- |
| Compilar | Pico SDK 1.5.1 + CMake + Ninja | Arduino IDE ou `arduino-cli` |
| Gravar | segurar BOOTSEL, copiar `.uf2` | bootloader serial, pelo USB |
| Simulador | extensão Wokwi do VS Code | os dois: extensão do VS Code **ou** wokwi.com (compila na nuvem) |
| Organização | vários `.c`/`.h` | **um `.ino` só**, para caber num paste |

A última linha é o motivo de o código Arduino estar num arquivo só, ainda
que a versão RP2040 seja modular: colar dois arquivos no wokwi.com e apertar
play é o caminho mais curto entre a ideia e ver a coisa funcionando. Mas com
o `arduino-cli` instalado o simulador local do VS Code também roda esta
versão — a extensão Wokwi nunca compilou nada, ela só carrega o binário
pronto, e o `.hex` do avr-gcc serve tão bem quanto o `.uf2` do Pico SDK.

**Ocupação, medida na compilação:** 9202 bytes de programa (28 % do UNO) e
465 bytes de RAM (22 %), sobrando 1583. Contra os 85 KB do binário RP2040 —
que tem 2 MB de flash e 264 KB de RAM para gastar.

## O que NÃO mudou

Vale listar, porque foi o objetivo: máquina de estados, ordenação das
chegadas por carimbo antes de numerar, a regra da primeira borda na largada,
`TEMPO_MIN_MS`, os três caminhos de fim de prova, o rearme pela porta, o
teste de fiação no boot com verificação de ACK, a corrida demo entrando pelo
mesmo caminho das chegadas reais, o `REFRESH_CORRIDA_MS` de 43, os sons e o
formato do tempo. Os nomes das funções são os mesmos, em camelCase.

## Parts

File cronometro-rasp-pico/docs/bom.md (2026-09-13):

# Lista de material e cuidados elétricos

Vale para as duas versões do projeto (RP2040 e Arduino). Onde a tensão de
trabalho muda alguma coisa, está marcado.

## Material

| Qtd | Item | Observação |
| --- | --- | --- |
| 1 | Módulo RP2040 **ou** Arduino UNO/Nano | um dos dois; ver o README da raiz |
| 6 | Módulo display TM1637, 4 dígitos | dos 10 do pacote |
| 6 | **Módulo sensor IR TCRT5000** (VCC, GND, D0, A0) | só VCC, GND e D0 são ligados — ver Aviso 3 |
| 1 | Microswitch com alavanca | na porta que solta os carrinhos |
| 1 | Botão táctil (opcional) | TESTE / rearma |
| 1 | Buzzer passivo (opcional) | |
| 1 | Regulador 3,3 V AMS1117-3.3 | **recomendado na versão RP2040** — ver Aviso 2 |
| — | Fio, barra de pinos, fonte USB 5 V | |
| (10) | Módulos LDR já comprados | ficam de reserva: o TCRT5000 os substituiu |

## Aviso 1 — no RP2040, alimente tudo em 3,3 V, nunca 5 V

> **Este aviso é só da versão RP2040.** No Arduino o problema não existe:
> o ATmega328P é uma peça de 5 V, então o TM1637 vai em 5 V, na tensão
> nativa dele, e ainda fica mais brilhante.

O TM1637 funciona em 5 V, e é tentador ligá-lo no VBUS para os dígitos
ficarem mais brilhantes. **Não faça isso.** O DIO é bidirecional e o módulo
tem um pull-up interno para a própria alimentação: em 5 V, a linha DIO
descansa em 5 V, e é ela que entra direto no GPIO do RP2040 — que **não é
tolerante a 5 V**. Funciona por um tempo e depois mata o pino.

Em 3,3 V os dígitos ficam um pouco menos brilhantes e é só isso.

**Vale igual para o TCRT5000.** O D0 dele é a saída do LM393 em coletor
aberto, com pull-up para o VCC **do próprio módulo**. Alimentado em 5 V, o
D0 descansa em 5 V — de novo direto num GPIO que não tolera. Na versão
RP2040, displays **e** sensores vão em 3,3 V. O LM393 trabalha em 3,3 V
sem ressalva.

## Aviso 2 — consumo: displays e sensores ficam acesos o tempo todo

Os dois consumidores grandes são contínuos: os dígitos do TM1637 e o **LED
infravermelho de cada TCRT5000, que nunca apaga**. No módulo usado aqui o resistor desse LED é o marcado `181` (180 Ω), o que dá:

| | por módulo, 3,3 V | seis, 3,3 V | por módulo, 5 V | seis, 5 V |
| --- | --- | --- | --- | --- |
| TCRT5000 (LED IR + LED de força) | ~13 mA | ~80 mA | ~24 mA | ~145 mA |
| TM1637, brilho 4 | ~15–25 mA | ~90–150 mA | ~20–30 mA | ~120–180 mA |

São estimativas a partir dos resistores e do brilho — **meça** com tudo
aceso antes de fechar a caixa.

**Na versão RP2040** a soma, com o próprio RP2040, fica entre 200 e 260 mA
no pino 3V3, e a Raspberry recomenda não passar de ~300 mA ali. O teste de
fiação do boot, com todos os segmentos e pontos acesos, chega perto disso.
Por isso a recomendação é um **regulador 3,3 V separado** (AMS1117-3.3
alimentado pelo VBUS) para displays e sensores, com o **GND em comum** com o
Pico, deixando o 3V3 do Pico só para ele. Na RP2040 roxa isso pesa mais: o
regulador dela é um linear pequeno, e 250 mA descendo de 5 V para 3,3 V
viram calor. Esquecer a massa comum é a receita clássica para o TM1637
mostrar lixo.

**Na versão Arduino**, tudo em 5 V dá uns 300–380 mA. Por **USB** passa (o
polifusível é de 500 mA). Pelo **conector DC de 12 V**, não: o regulador da
placa teria que dissipar mais de 2 W. Alimente por USB, ou ponha 5 V direto
no pino 5 V.

`TM1637_BRILHO` está em **4** (de 0 a 7). Subir o brilho é o jeito mais
rápido de estourar essa conta.

## Aviso 3 — o sensor de chegada: TCRT5000

**Decidido: módulo TCRT5000** (a plaquinha com LM393 e trimpot), ligado pelo D0. O
raciocínio fica registrado aqui para a discussão não voltar depois.

### A conta

O tempo em que o carro tapa o sensor não depende do tamanho do sensor, e
sim do **comprimento do carro**: um Hot Wheels 1:64 tem ~68 mm. Somando uns
5 mm de feixe:

| Velocidade na chegada | Tempo com o feixe tapado |
| --- | --- |
| 2 m/s | 36 ms |
| 3 m/s | 24 ms |
| 4 m/s | 18 ms |

Agora o outro lado. No vídeo original os seis tempos foram 3.514, 3.630,
3.663, 3.680, 3.721 e 3.820 s. As diferenças entre colocações vizinhas:
**116, 33, 17, 41 e 99 ms**. Ou seja, a disputa mais apertada da prova foi
decidida por **17 ms** — e esse é o número que o sensor precisa resolver com
folga. Para não decidir nada no lugar do carro, o erro entre raias deveria
ficar abaixo de uns 2 ms.

### Por que não LDR

Um LDR de sulfeto de cádmio é um fotocondutor: a resistência muda porque
portadores são presos e liberados na rede cristalina, e isso é lento.

1. **O carro tapando a luz é a direção lenta.** O LDR sobe de resistência
   (escurecendo) bem mais devagar do que desce (clareando) — dezenas de
   milissegundos para chegar perto do valor de escuro.
2. **O que importa é quando ele cruza o limiar, não quando estabiliza.** Dá
   para ganhar tempo ajustando o trimpot com o comparador quase virando. Mas
   aí o ajuste fica na beira: qualquer mudança de luz do ambiente vira
   disparo falso ou chegada perdida.
3. **O erro entre raias é o que estraga, não o erro absoluto.** Se os seis
   sensores atrasassem exatamente igual, o atraso viraria um deslocamento
   constante: some na colocação e some na comparação entre raias. O problema
   é que **não atrasam igual** — LDRs do mesmo lote variam de 30 a 50 % na
   resistência, e cada trimpot fica num ponto ligeiramente diferente. Essa
   diferença é da mesma ordem dos 17 ms que separam duas colocações.
4. **E o modo de falha é o pior possível:** quanto mais rápido o carro,
   menor a janela de sombra. Se algum carro não conseguir manter o sensor
   tapado tempo suficiente para o LDR cruzar o limiar, será justamente **o
   carro mais rápido** que não vai registrar. Uma falha que escolhe o
   vencedor é pior do que uma falha aleatória.

### Por que o TCRT5000 serve

O TCRT5000 é um LED infravermelho e um fototransistor lado a lado, olhando
para o mesmo lado; o módulo acrescenta um comparador LM393 com trimpot. O
fototransistor responde em microssegundos, e o comparador também: a borda
chega ao pino em bem menos de 1 ms, muito abaixo dos 17 ms que decidem uma
colocação.

### O cuidado: ele é refletivo

Ao contrário de uma barreira (LED de um lado, receptor do outro), o TCRT5000
dispara quando **alguma coisa reflete** o infravermelho de volta. O ponto
exato em que ele vira depende de quanto o fundo do carro reflete e de quão
perto ele passa. É administrável, mas precisa ser feito:

1. **Monte por baixo da pista, olhando para cima**, por um furo no piso da
   raia, com o fundo do carro passando a **2–5 mm** do sensor. O TCRT5000 tem
   o pico de sensibilidade em ~2,5 mm e perde muito a partir de ~10 mm: a
   distância pesa mais do que a cor.
2. **Ajuste os seis trimpots com o mesmo carro** parado sobre cada sensor:
   gire até o LED de saída acender com o carro e apagar com a raia vazia, e
   deixe no meio dessa faixa.
3. **Teste com a frota de verdade.** Fundo preto fosco reflete pouco. Se
   algum carro não disparar, aproxime o sensor antes de mexer no trimpot.
4. **Tire luz direta de cima dos sensores.** Sol e lâmpada incandescente têm
   muito infravermelho.
5. **Na versão RP2040 os TCRT5000 vão em 3,3 V** (Aviso 1), o que dá menos
   corrente no LED IR e um pouco menos de alcance: fique no lado de baixo da
   faixa de distância, 2–3 mm.

### Polaridade: o D0 cai para 0 com o carro

Sem carro nada reflete e o D0 fica em **1**; com o carro em cima o
comparador vira, o D0 vai a **0** e o LED de saída do módulo acende. Por
isso `SENSOR_NIVEL_CARRO` é **0** nas duas versões.

Há lotes invertidos. Antes de montar as seis raias, confira num módulo só:
se o LED acende com o carro, está certo. Sem multímetro: com o firmware
rodando e a prova armada, segurar um carrinho sobre o sensor da raia 1 por
2 s tem que disparar a corrida demo.

O pino **A0** do módulo (a tensão analógica do fototransistor) fica solto.

### Se algum carro teimar em não disparar: a barreira

Se, depois de aproximar e ajustar, algum carro continuar falhando, aquele
ponto pode virar uma **barreira**: LED IR de um lado da raia, fototransistor
do outro. A borda passa a ser geométrica (o para-choque cortou o feixe) e não
depende do carro. **O firmware não muda** — só a polaridade: na barreira o
pino fica em 0 com o feixe passando e vai a 1 com o carro, então
`SENSOR_NIVEL_CARRO` volta para 1.

```
V+ ──[220 Ω em 3,3 V / 330 Ω em 5 V]── LED IR ── GND   (um lado da raia)

V+ ──[10 kΩ]──┬──────────── pino do sensor           (outro lado)
              │
         fototransistor (coletor em cima, emissor no GND)
```

### Como conferir na bancada, antes de fazer as seis

1. Solte **o mesmo carro** cinco vezes na **mesma raia** e olhe a dispersão
   dos tempos no log serial. É o ruído de base da raia.
2. Solte **o mesmo carro** uma vez em cada raia. As diferenças aqui são
   atrito da raia **mais** viés do sensor, misturados.
3. Para separar os dois: **troque os sensores de raia** e repita. O que
   andar junto com o sensor é viés de sensor; o que ficar na raia é atrito.

Se o viés de sensor passar de uns poucos milissegundos, a colocação de uma
chegada apertada não é confiável — e é aí que o infravermelho paga.

## Sobre o display: dois-pontos ou ponto decimal?

Existem dois tipos de módulo TM1637 de 4 dígitos vendidos com a mesma
descrição:

- o **azul**, de relógio — só um par de dois-pontos no meio;
- o **preto de 0,56"**, com **dois headers**, um de cada lado, os dois com
  CLK, DIO, GND e 5V (o que facilita encadear um display no outro). O vidro
  dele tem um ponto embaixo de cada dígito, além do dois-pontos.

Só que ter o pontinho no vidro não garante que ele esteja ligado ao TM1637:
em vários lotes do preto só o dois-pontos está. Não dá para saber olhando,
por isso o teste de fiação do boot acende **tudo** — todos os segmentos e
todos os pontos. Ligue uma vez e veja:

| O que acendeu no primeiro quadro | `DISPLAY_PONTO_DECIMAL` | O tempo sai |
| --- | --- | --- |
| um ponto embaixo de cada dígito | `1` | `3.721`, como no vídeo |
| só os dois pontinhos do meio | `0` (padrão) | `3721`, lê-se 3,721 s |

No simulador sempre parece o segundo caso, porque a peça do Wokwi é a de
relógio. Acender o dois-pontos num tempo abaixo de 10 s leria `37:21`, que é
pior do que não ter separador.

Acima de 10 s o separador acende nos dois casos, de propósito: sem ele,
`1234` tanto seria 1,234 s quanto 12,34 s.

## Se um display não acender

O firmware confere o **ACK** de cada TM1637 e avisa no log serial qual raia
não respondeu. Como o CLK é comum, o padrão da falha diz onde está o defeito:

| Sintoma | Onde olhar |
| --- | --- |
| **Um** display apagado, os outros bem | o DIO daquele display, ou a alimentação dele |
| **Todos** apagados | o CLK (GP9), ou a massa comum |
| Todos mostram lixo / piscam junto | massa comum ruim, ou alimentação com queda |
| Um mostra o número de outra raia no teste inicial | dois DIO trocados |

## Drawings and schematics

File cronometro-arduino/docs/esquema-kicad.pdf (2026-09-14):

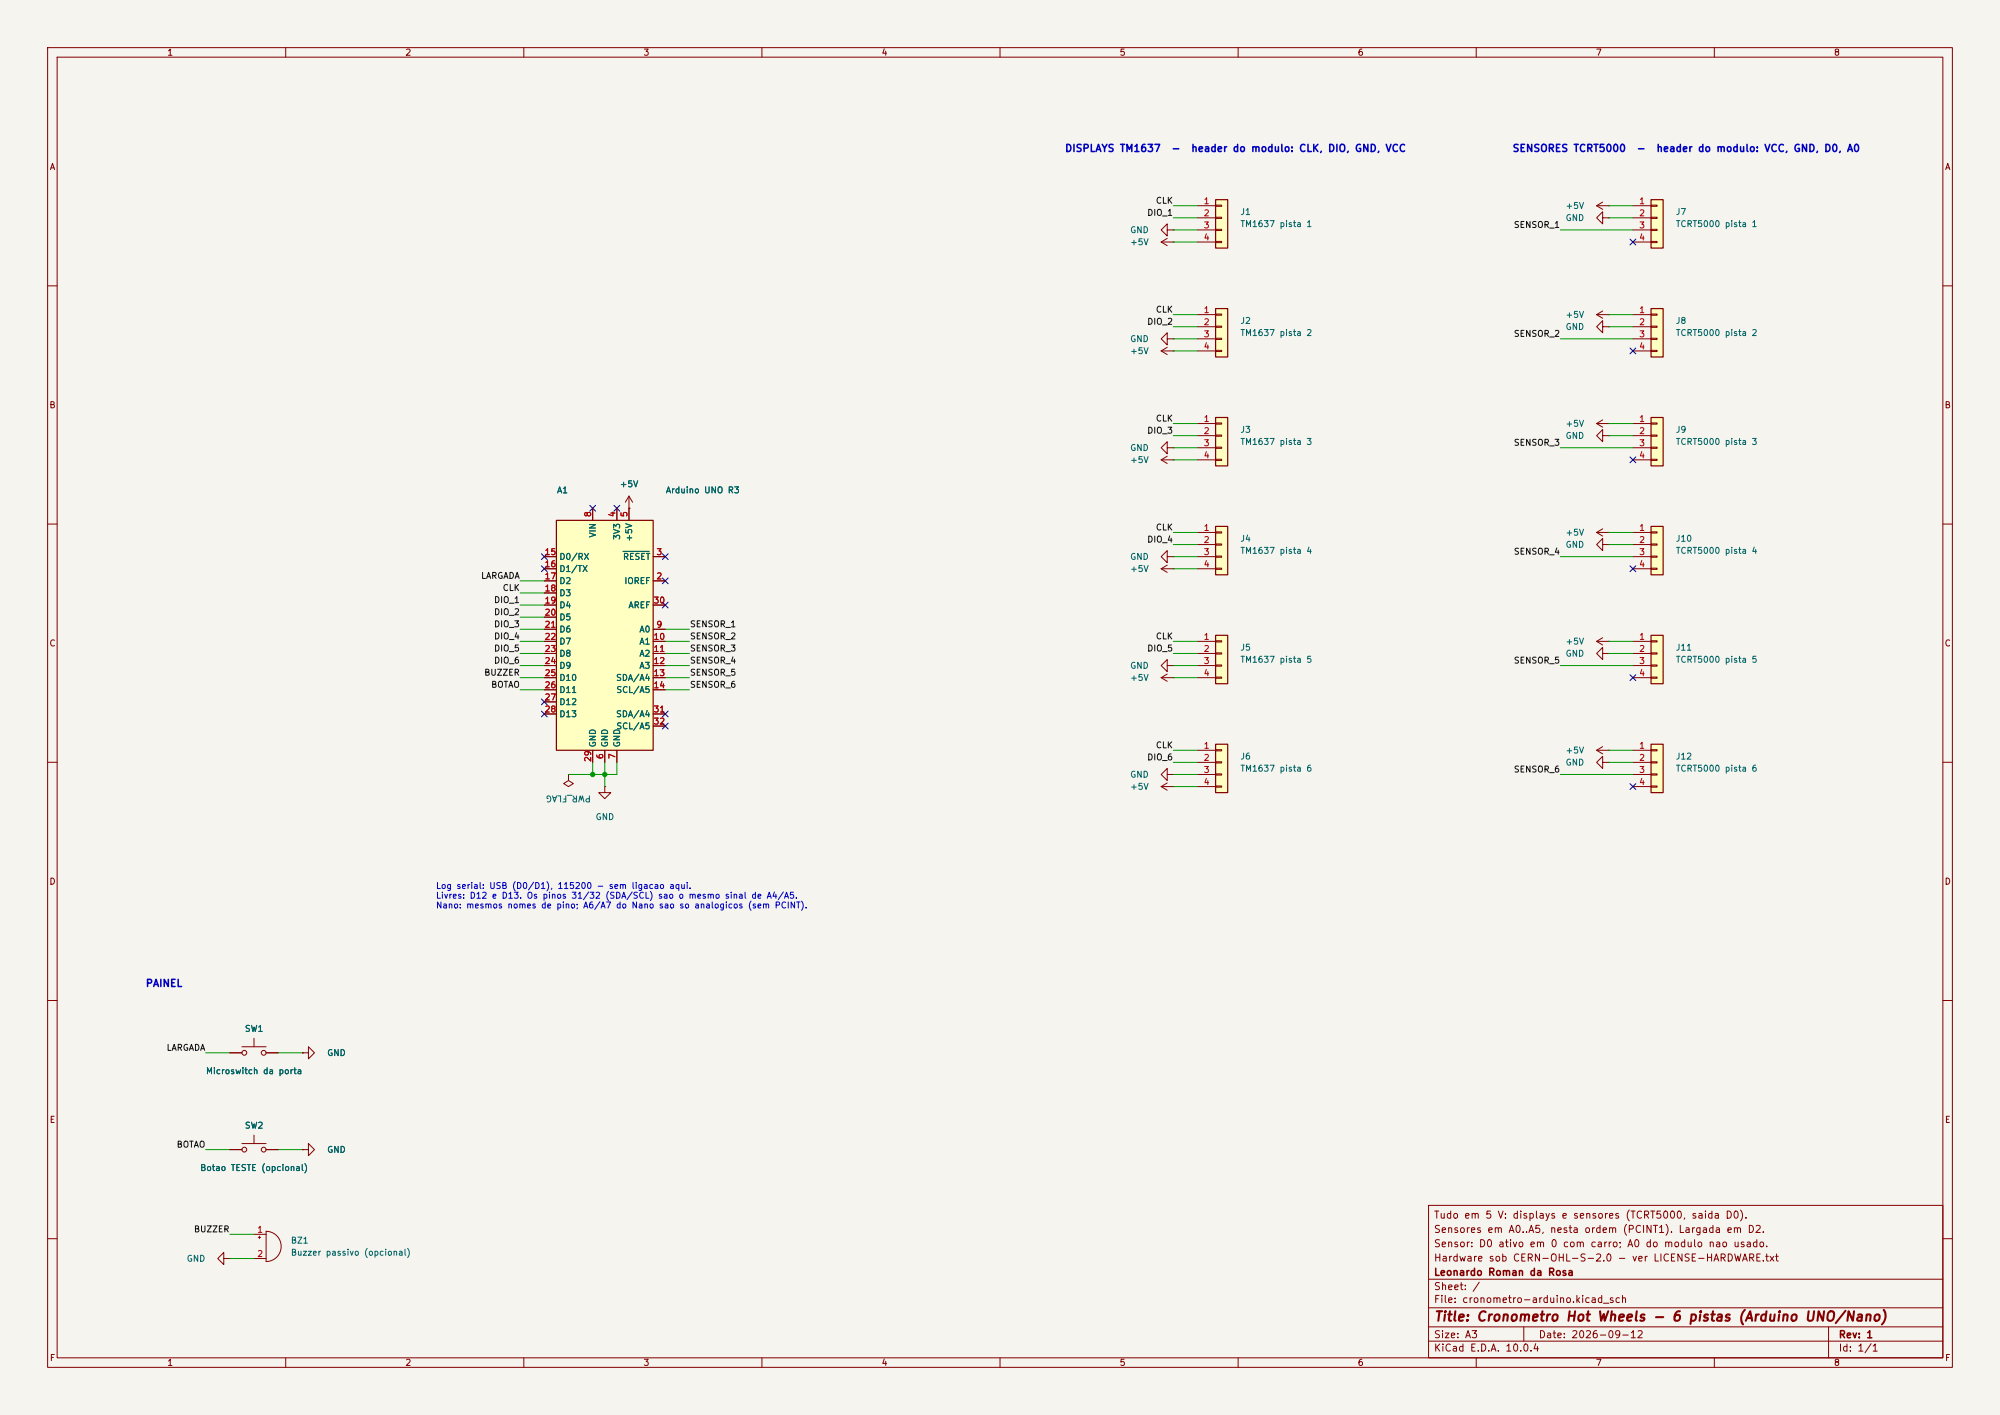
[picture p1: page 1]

SENSOR_1 CLK DISPLAYS TM1637 - header do modulo: CLK, DIO, GND, VCC

SENSORES TCRT5000 - header do modulo: VCC, GND, D0, A0

TCRT5000 pista 3 +5V GND +5V GND +5V GND

Log serial: USB (D0/D1), 115200 - sem ligacao aqui. Livres: D12 e D13. Os pinos 31/32 (SDA/SCL) sao o mesmo sinal de A4/A5. Nano: mesmos nomes de pino; A6/A7 do Nano sao so analogicos (sem PCINT).

Tudo em 5 V: displays e sensores (TCRT5000, saida D0).
Sensores em A0..A5, nesta ordem (PCINT1). Largada em D2.
Sensor: D0 ativo em 0 com carro; A0 do modulo nao usado.
Hardware sob CERN-OHL-S-2.0 - ver LICENSE-HARDWARE.txt
Leonardo Roman da Rosa
Sheet: /
File: cronometro-arduino.kicad_sch
Title: Cronometro Hot Wheels - 6 pistas (Arduino UNO/Nano)

Size: A3 | Rev: 1
KiCad E.D.A. 10.0.4 | Id: 1/1 | F Date: 2026-09-12

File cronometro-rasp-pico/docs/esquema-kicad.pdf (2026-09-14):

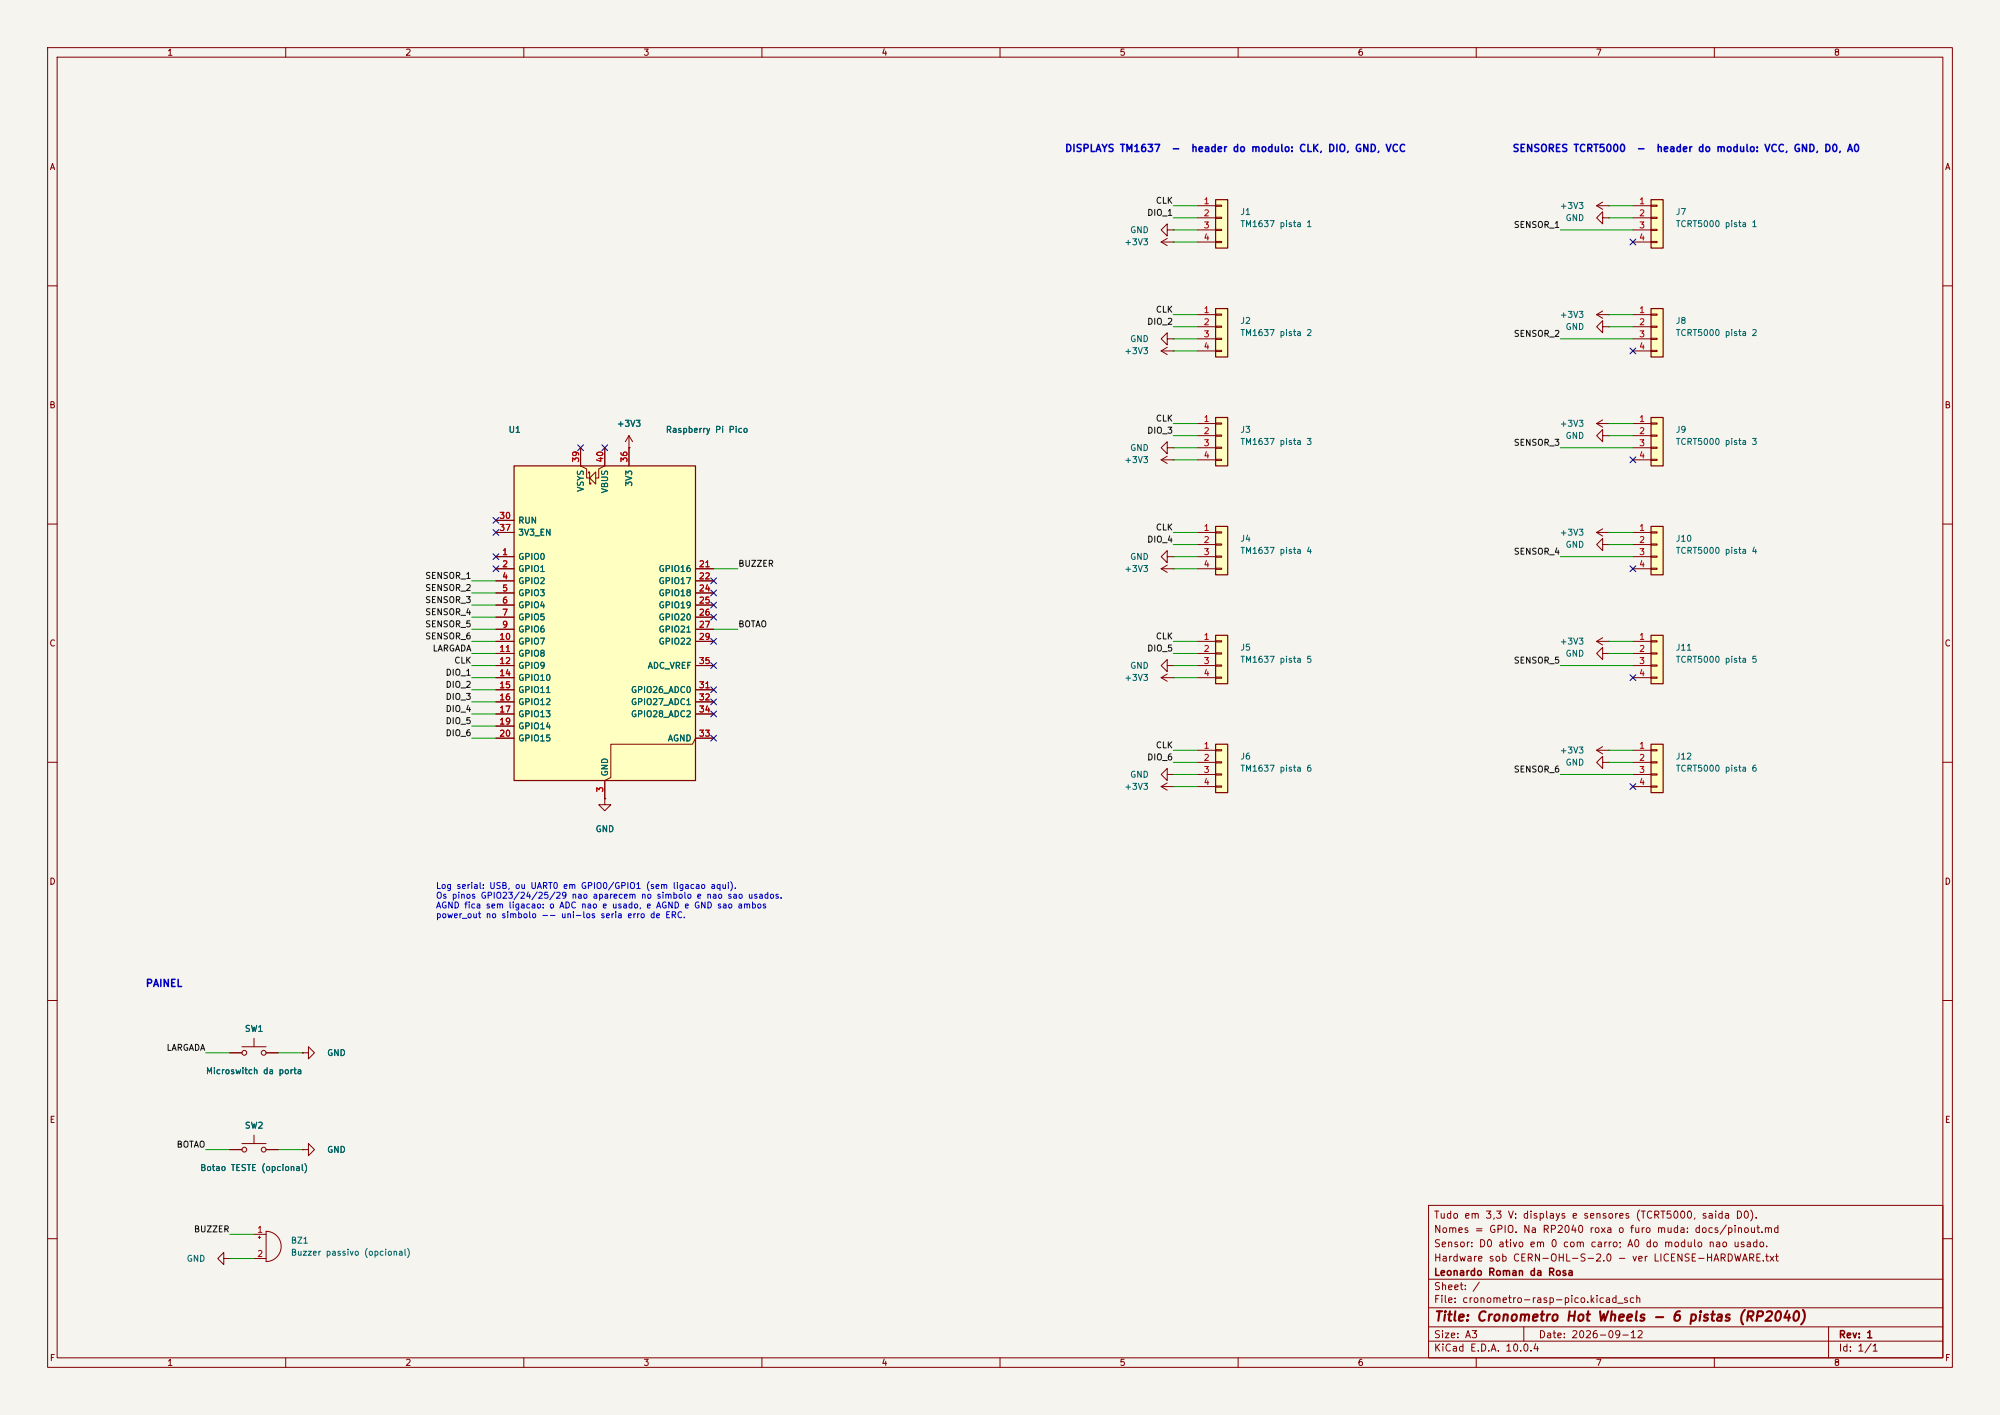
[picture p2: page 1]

SENSOR_1 DISPLAYS TM1637 - header do modulo: CLK, DIO, GND, VCC

SENSORES TCRT5000 - header do modulo: VCC, GND, D0, A0

Log serial: USB, ou UART0 em GPIO0/GPIO1 (sem ligacao aqui). Os pinos GPIO23/24/25/29 nao aparecem no simbolo e nao sao usados. AGND fica sem ligacao: o ADC nao e usado, e AGND e GND sao ambos power_out no simbolo -- uni-los seria erro de ERC.

Tudo em 3,3 V: displays e sensores (TCRT5000, saida D0).
Nomes = GPIO. Na RP2040 roxa o furo muda: docs/pinout.md
Sensor: D0 ativo em 0 com carro; A0 do modulo nao usado.
Hardware sob CERN-OHL-S-2.0 - ver LICENSE-HARDWARE.txt
Leonardo Roman da Rosa
Sheet: /
File: cronometro-rasp-pico.kicad_sch
Title: Cronometro Hot Wheels - 6 pistas (RP2040)

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

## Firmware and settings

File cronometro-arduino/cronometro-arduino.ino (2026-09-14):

/* SPDX-License-Identifier: GPL-3.0-or-later */
/* Copyright (C) 2026 Leonardo Roman da Rosa */
/*
 * Cronometro de 6 pistas para pista de carrinhos Hot Wheels.
 * Versao Arduino UNO / Nano (ATmega328P, 16 MHz).
 *
 * Um microswitch na porta de largada marca o t0; um modulo infravermelho
 * TCRT5000 no fim de cada pista marca a chegada; seis displays TM1637
 * mostram a colocacao e depois o tempo.
 *
 * Gemeo da versao RP2040 (pasta cronometro-rasp-pico), com o mesmo
 * comportamento. As diferencas de plataforma estao em docs/diferencas-rp2040.md.
 *
 * Arquivo unico de proposito: assim cabe num unico "colar" no wokwi.com,
 * que compila na nuvem e nao precisa de nada instalado.
 */
#include <avr/interrupt.h>

/* =================================================================== */
/* CONFIGURACAO -- e aqui que se mexe                                   */
/* =================================================================== */

const uint8_t N_PISTAS = 6;

/*
 * PINOS
 *
 * Os sensores NAO tem tabela: o D0 deles precisa estar em A0..A5, nesta
 * ordem, porque sao a PORTC inteira e assim os seis cabem numa unica
 * interrupcao de mudanca de pino (PCINT1). O ATmega328P so tem DUAS
 * interrupcoes externas de verdade (D2 e D3) -- nao dariam para seis pistas.
 * A pista 1 e A0, a pista 6 e A5. O pino A0 do modulo (analogico) fica solto.
 */
const uint8_t PIN_LARGADA = 2;   /* microswitch da porta -- tem que ser D2
                                    (INT0) ou D3 (INT1)                  */
const uint8_t PIN_TM_CLK  = 3;   /* CLK comum aos seis displays          */
const uint8_t PIN_TM_DIO[N_PISTAS] = { 4, 5, 6, 7, 8, 9 };
const uint8_t PIN_BUZZER  = 10;  /* buzzer passivo (opcional)            */
const uint8_t PIN_BOTAO   = 11;  /* botao TESTE / REARMA (opcional)      */

#define USAR_BUZZER 1            /* 0 desliga o som e libera o D10       */
#define USAR_BOTAO  1            /* 0 desliga o botao e libera o D11     */

/*
 * POLARIDADES
 *
 * Nivel do D0 do modulo quando o carrinho esta SOBRE o sensor.
 *
 * No TCRT5000 o LM393 tem saida em coletor aberto e o modulo ja traz o
 * pull-up: sem carro nada reflete e o D0 fica em 1; com o carro em cima o
 * fototransistor conduz, o comparador vira e o D0 cai para 0. Ou seja:
 * carro = borda de DESCIDA, e o LED de saida do modulo acende.
 *
 * CONFIRA NO SEU MODULO antes de montar as seis pistas -- ha lote que sai
 * invertido. Ligue um so, ponha um carrinho em cima e veja o LED: se ele
 * acender com o carro, este valor esta certo. Sem multimetro: com a prova
 * armada, segurar um carrinho sobre o sensor da pista 1 por 2 s tem que
 * disparar a corrida demo (ver GESTO_DEMO_MS).
 */
#ifndef SENSOR_NIVEL_CARRO      /* o release compila variantes com -D */
#define SENSOR_NIVEL_CARRO 0
#endif

/*
 * Nivel do pino de largada com a porta ABERTA.
 * Microswitch entre o pino e o GND, com pull-up interno: porta fechada =
 * contato fechado = 0; porta abre = 1.
 */
#define LARGADA_NIVEL_ABERTA 1

/* TEMPOS (ms) */
const uint16_t TEMPO_MIN_MS       = 150;   /* chegada antes disso = ruido  */
const uint16_t TEMPO_LIMITE_MS    = 15000; /* fim da prova por tempo       */
const uint16_t ESPERA_APOS_1o_MS  = 8000;  /* fim apos o primeiro colocado */

const uint16_t MOSTRA_POSICAO_MS  = 4500;
const uint16_t MOSTRA_TEMPO_MS    = 7000;
const uint16_t RESULTADO_MIN_MS   = 23000; /* rearme automatico, so com a
                                              porta ja fechada            */
const uint16_t PISCA_MS           = 400;

/*
 * Periodo do cronometro correndo na tela. NAO use numero redondo: com 50 ms
 * o ultimo digito do milissegundo fica parado em 0 e o penultimo so alterna
 * 0/5, o que parece display quebrado. Com 43 os dez algarismos aparecem.
 */
const uint8_t  REFRESH_CORRIDA_MS = 43;

const uint16_t DEBOUNCE_BOTAO_MS  = 20;    /* so do botao de teste: a
                                              largada nao precisa, ver ISR */
const uint16_t BOTAO_LONGO_MS     = 1000;  /* pressao longa = corrida demo */
const uint16_t GESTO_DEMO_MS      = 2000;  /* carrinho sobre o sensor 1    */

/* DISPLAYS */
const uint8_t TM1637_BRILHO = 4;  /* 0..7 -- mexe direto no consumo       */
const uint8_t TM1637_BIT_US = 5;  /* meio periodo do clock bit-bang       */

/*
 *   0 = so o dois-pontos central e ligado: o tempo sai "3721" e se le
 *       3,721 s. E o que o TM1637 do Wokwi modela.
 *   1 = cada digito tem o proprio ponto ligado -> "3.721", como no video.
 *
 * O vidro do modulo preto de 0,56" TEM os pontinhos, mas em varios lotes
 * eles nao estao ligados no TM1637 -- so o dois-pontos esta. Nao da para
 * saber olhando: o teste de fiacao do boot acende TODOS os segmentos e
 * TODOS os pontos (0xFF em cada digito) justamente para isso. Ligue uma vez
 * e veja o que acendeu:
 *   um ponto embaixo de cada digito  -> ponha 1
 *   so os dois pontinhos do meio     -> deixe 0
 * No simulador sempre parece o caso 0, porque a peca do Wokwi e a de relogio.
 *
 * Acima de 10 s o separador acende nos dois casos -- ver dispTempo().
 */
#ifndef DISPLAY_PONTO_DECIMAL   /* o release compila variantes com -D */
#define DISPLAY_PONTO_DECIMAL 0
#endif

/* CORRIDA DEMO */
const uint16_t DEMO_MS_MIN = 2400;
const uint16_t DEMO_MS_MAX = 4600;

const uint16_t SOM_LARGADA_HZ = 330,  SOM_LARGADA_MS = 600;
const uint16_t SOM_CHEGADA_HZ = 1400, SOM_CHEGADA_MS = 70;
const uint16_t SOM_FIM_HZ     = 220,  SOM_FIM_MS     = 450;
const uint16_t SOM_BOOT_HZ    = 880,  SOM_BOOT_MS    = 80;

const uint32_t TEMPO_INVALIDO = 0xFFFFFFFFUL;

/* =================================================================== */
/* TM1637 -- protocolo de dois fios                                     */
/* =================================================================== */
/*
 * O TM1637 nao tem endereco: quem seleciona o chip e a linha DIO, porque a
 * transacao so comeca numa condicao de START (DIO descendo com CLK alto).
 * Por isso os seis displays dividem o mesmo CLK -- enquanto se escreve numa
 * pista, os outros cinco veem o clock com o DIO deles parado em nivel alto
 * e ignoram tudo. Sao 7 pinos em vez de 12.
 *
 * CLK e push-pull (so o mestre o dirige). DIO e dreno aberto emulado: para
 * soltar a linha o pino vira entrada com pull-up; para puxar para baixo,
 * primeiro se desliga o pull-up (digitalWrite LOW com o pino ainda entrada)
 * e so entao ele vira saida. Essa ordem importa: fazer pinMode(OUTPUT) com
 * o bit de PORT ainda em 1 faria o pino dirigir 5 V na linha.
 */
#define TM_DLY() delayMicroseconds(TM1637_BIT_US)

static inline void dioSolta(uint8_t p) { pinMode(p, INPUT_PULLUP); }
static inline void dioBaixo(uint8_t p) { digitalWrite(p, LOW); pinMode(p, OUTPUT); }
static inline void clkAlto(void)       { digitalWrite(PIN_TM_CLK, HIGH); }
static inline void clkBaixo(void)      { digitalWrite(PIN_TM_CLK, LOW); }

static void tmInicio(uint8_t dio)   /* START: DIO desce com CLK alto */
{
    clkAlto(); dioSolta(dio); TM_DLY();
    dioBaixo(dio);            TM_DLY();
    clkBaixo();               TM_DLY();
}

static void tmFim(uint8_t dio)      /* STOP: DIO sobe com CLK alto */
{
    clkBaixo(); dioBaixo(dio); TM_DLY();
    clkAlto();                 TM_DLY();
    dioSolta(dio);             TM_DLY();
}

static bool tmByte(uint8_t dio, uint8_t b)
{
    for (uint8_t i = 0; i < 8; i++) {        /* LSB primeiro */
        clkBaixo();
        if (b & 1) dioSolta(dio); else dioBaixo(dio);
        b >>= 1;
        TM_DLY();
        clkAlto();
        TM_DLY();
    }
    clkBaixo();                              /* ACK no nono clock */
    dioSolta(dio);
    TM_DLY();
    clkAlto();
    TM_DLY();
    const bool ack = (digitalRead(dio) == LOW);
    clkBaixo();
    TM_DLY();
    return ack;
}

static bool tmBrilho(uint8_t dio, uint8_t brilho, bool ligado)
{
    tmInicio(dio);
    const bool ack = tmByte(dio, 0x80 | (ligado ? 0x08 : 0x00) | (brilho & 0x07));
    tmFim(dio);
    return ack;
}

static bool tmSegmentos(uint8_t dio, const uint8_t seg[4])
{
    tmInicio(dio);
    bool ack = tmByte(dio, 0x40);            /* escrita com auto-incremento */
    tmFim(dio);

    tmInicio(dio);
    ack &= tmByte(dio, 0xC0);                /* comeca no digito 0 */
    for (uint8_t i = 0; i < 4; i++) ack &= tmByte(dio, seg[i]);
    tmFim(dio);

    return ack;
}

/* =================================================================== */
/* Display: fonte de 7 segmentos e formatacao                           */
/* =================================================================== */
#define PONTO 0x80

static bool ackOk[N_PISTAS];

/* bit0=a (topo) ... bit6=g (meio), bit7=ponto/dois-pontos */
static uint8_t segChar(char c)
{
    switch (c) {
    case '0': return 0x3F;  case '1': return 0x06;  case '2': return 0x5B;
    case '3': return 0x4F;  case '4': return 0x66;  case '5': return 0x6D;
    case '6': return 0x7D;  case '7': return 0x07;  case '8': return 0x7F;
    case '9': return 0x6F;
    case ' ': return 0x00;  case '-': return 0x40;  case '_': return 0x08;
    case 'A': return 0x77;  case 'b': return 0x7C;  case 'C': return 0x39;
    case 'd': return 0x5E;  case 'E': return 0x79;  case 'F': return 0x71;
    case 'H': return 0x76;  case 'h': return 0x74;  case 'I': return 0x06;
    case 'L': return 0x38;  case 'n': return 0x54;  case 'o': return 0x5C;
    case 'P': return 0x73;  case 'r': return 0x50;  case 'S': return 0x6D;
    case 't': return 0x78;  case 'U': return 0x3E;  case 'u': return 0x1C;
    default:  return 0x00;
    }
}

static void dispEnvia(uint8_t pista, const uint8_t seg[4])
{
    if (pista >= N_PISTAS) return;
    ackOk[pista] = tmSegmentos(PIN_TM_DIO[pista], seg);
}

static void dispTexto(uint8_t pista, const char *s4)
{
    uint8_t seg[4] = { 0, 0, 0, 0 };
    for (uint8_t i = 0; i < 4 && s4[i] != '\0'; i++) seg[i] = segChar(s4[i]);
    dispEnvia(pista, seg);
}

/* Acende tudo que o modulo tem: 7 segmentos mais ponto/dois-pontos. E o
   teste de fiacao do boot, e tambem o que revela se o modulo liga um ponto
   por digito ou so o dois-pontos central. */
static void dispTudoAceso(uint8_t pista)
{
    const uint8_t seg[4] = { 0xFF, 0xFF, 0xFF, 0xFF };
    dispEnvia(pista, seg);
}

static void dispTextoTodos(const char *s4)
{
    for (uint8_t p = 0; p < N_PISTAS; p++) dispTexto(p, s4);
}

static void dispTempo(uint8_t pista, uint32_t ms)
{
    uint8_t seg[4];

    if (ms == TEMPO_INVALIDO || ms >= 100000UL) {
        dispTexto(pista, "----");
        return;
    }

    if (ms < 10000UL) {                      /* S.mmm */
        seg[0] = segChar('0' + (uint8_t)(ms / 1000UL));
        seg[1] = segChar('0' + (uint8_t)((ms / 100UL) % 10UL));
        seg[2] = segChar('0' + (uint8_t)((ms / 10UL)  % 10UL));
        seg[3] = segChar('0' + (uint8_t)(ms % 10UL));
#if DISPLAY_PONTO_DECIMAL
        seg[0] |= PONTO;
#endif
    } else {                                 /* SS.mm */
        seg[0] = segChar('0' + (uint8_t)(ms / 10000UL));
        seg[1] = segChar('0' + (uint8_t)((ms / 1000UL) % 10UL));
        seg[2] = segChar('0' + (uint8_t)((ms / 100UL)  % 10UL));
        seg[3] = segChar('0' + (uint8_t)((ms / 10UL)   % 10UL));
        /*
         * Aqui o separador acende nos DOIS tipos de modulo, de proposito.
         * Sem separador nenhum, "1234" seria 1,234 s ou 12,34 s -- nao da
         * para saber. Aceso, o modulo de ponto mostra 12.34 e o de relogio
         * mostra 12:34; os dois se leem igual, e o separador apagado passa
         * a significar "este tempo esta no formato S.mmm".
         */
#if DISPLAY_PONTO_DECIMAL
        seg[1] |= PONTO;
#else
        /* No modulo de relogio o dois-pontos e um so, e qual digito carrega
           o bit que o acende muda de implementacao para implementacao.
           Marcar os dois primeiros acende do mesmo jeito. */
        seg[0] |= PONTO;
        seg[1] |= PONTO;
#endif
    }
    dispEnvia(pista, seg);
}

static void dispPosicao(uint8_t pista, uint8_t pos)
{
    char s[5] = "    ";
    if (pos >= 1 && pos <= 9) s[3] = (char)('0' + pos);
    dispTexto(pista, s);
}

static void dispInit(void)
{
    pinMode(PIN_TM_CLK, OUTPUT);
    digitalWrite(PIN_TM_CLK, HIGH);
    for (uint8_t p = 0; p < N_PISTAS; p++) dioSolta(PIN_TM_DIO[p]);

    /* So depois que os seis DIO existem como pino e que da para falar com
       qualquer um: o CLK e comum, e um DIO ainda flutuando poderia ser lido
       como um START pelo modulo vizinho. */
    for (uint8_t p = 0; p < N_PISTAS; p++) {
        ackOk[p] = tmBrilho(PIN_TM_DIO[p], TM1637_BRILHO, true);
        dispTexto(p, "    ");
    }
}

/* =================================================================== */
/* Som -- nao bloqueante                                                */
/* =================================================================== */
#if USAR_BUZZER
static unsigned long somFimMs;
static bool          somTocando;

static void somBip(uint16_t hz, uint16_t ms)
{
    if (hz == 0 || ms == 0) return;
    tone(PIN_BUZZER, hz);
    somFimMs   = millis() + ms;
    somTocando = true;
}

static void somTick(void)
{
    if (!somTocando) return;
    if ((long)(millis() - somFimMs) < 0) return;
    noTone(PIN_BUZZER);
    somTocando = false;
}
#else
static void somBip(uint16_t hz, uint16_t ms) { (void)hz; (void)ms; }
static void somTick(void) {}
#endif

/* =================================================================== */
/* Estado                                                               */
/* =================================================================== */
enum estado_t { EST_ARMADO, EST_CORRENDO, EST_RESULTADO };
enum fase_t   { FASE_POSICAO, FASE_TEMPO };

struct pista_t {
    bool     chegou;
    uint32_t ms;        /* tempo desde a largada */
    uint8_t  posicao;   /* 1..6; 0 = nao chegou  */
};

/* --- compartilhado com as interrupcoes --- */
static volatile unsigned long largadaUs;
static volatile bool          largadaFlag;   /* porta abriu  */
static volatile bool          fechouFlag;    /* porta fechou */
static volatile unsigned long sensorUs[N_PISTAS];
static volatile bool          sensorFlag[N_PISTAS];
static volatile uint8_t       pincAnt;       /* ultimo estado de A0..A5 */

/* --- so do laco principal --- */
static estado_t estado;
static fase_t   fase;
static pista_t  pista[N_PISTAS];
static uint8_t  nChegadas;

static unsigned long t0Us;           /* instante da largada, em micros    */
static unsigned long tPrimeiroUs;    /* 1o colocado (0 = ninguem ainda)   */
static unsigned long tResultadoMs;
static unsigned long tFaseMs;
static unsigned long tRefreshMs;
static unsigned long tPiscaMs;
static bool          pisca;
static int8_t        armadoVisual;   /* -1 forca reescrita dos displays   */

static bool     demo;
static uint16_t demoMs[N_PISTAS];
static bool     sementeFeita;

#if USAR_BOTAO
static bool          botaoAntes, botaoTratado;
static unsigned long botaoDesdeMs;
#endif
static bool          gestoArmado;
static unsigned long gestoDesdeMs;

/* =================================================================== */
/* Interrupcoes -- so carimbam a hora. Toda decisao fica no laco.        */
/* =================================================================== */
/*
 * As seis barreiras estao na PORTC e compartilham a PCINT1. A ISR le a
 * porta inteira de uma vez e descobre quem mudou pelo XOR com a leitura
 * anterior -- uma unica interrupcao cobre as seis pistas.
 */
ISR(PCINT1_vect)
{
    const unsigned long agora = micros();
    const uint8_t atual = PINC & 0x3F;
    const uint8_t mudou = atual ^ pincAnt;
    pincAnt = atual;

    for (uint8_t i = 0; i < N_PISTAS; i++) {
        if (!(mudou & _BV(i))) continue;
        const bool alto = (atual & _BV(i)) != 0;
        if (alto == (SENSOR_NIVEL_CARRO != 0) && !sensorFlag[i]) {
            sensorUs[i]   = agora;
            sensorFlag[i] = true;
        }
    }
}

static void isrLargada(void)
{
    const unsigned long agora  = micros();
    const bool          aberta = (digitalRead(PIN_LARGADA) != LOW)
                                 == (LARGADA_NIVEL_ABERTA != 0);
    if (aberta) {
        /* A PRIMEIRA borda e a boa: o repique do microswitch vem depois
           dela, nunca antes. Por isso nao existe janela de debounce aqui. */
        if (!largadaFlag) {
            largadaUs   = agora;
            largadaFlag = true;
        }
    } else {
        fechouFlag = true;
    }
}

static void limpaSensores(void)
{
    for (uint8_t i = 0; i < N_PISTAS; i++) sensorFlag[i] = false;
}

static inline bool portaAberta(void)
{
    return (digitalRead(PIN_LARGADA) != LOW) == (LARGADA_NIVEL_ABERTA != 0);
}

static inline bool carroSobreSensor(uint8_t i)
{
    return ((PINC & _BV(i)) != 0) == (SENSOR_NIVEL_CARRO != 0);
}

/* =================================================================== */
/* Log serial                                                           */
/* =================================================================== */
static void serialTempo(uint32_t ms)
{
    Serial.print(ms / 1000UL);
    Serial.print('.');
    const uint16_t f = (uint16_t)(ms % 1000UL);
    if (f < 100) Serial.print('0');
    if (f < 10)  Serial.print('0');
    Serial.print(f);
    Serial.print(F(" s"));
}

/* =================================================================== */
/* Transicoes                                                           */
/* =================================================================== */
static void rearma(void)
{
    estado       = EST_ARMADO;
    armadoVisual = -1;
    pisca        = true;
    tPiscaMs     = millis();
    largadaFlag  = false;
    fechouFlag   = false;
    limpaSensores();
    Serial.println(F("[armado] esperando a porta abrir"));
}

static void iniciaCorrida(unsigned long t0, bool ehDemo)
{
    t0Us        = t0;
    tPrimeiroUs = 0;
    tRefreshMs  = 0;
    nChegadas   = 0;
    demo        = ehDemo;

    for (uint8_t i = 0; i < N_PISTAS; i++) {
        pista[i].chegou  = false;
        pista[i].ms      = TEMPO_INVALIDO;
        pista[i].posicao = 0;
    }
    limpaSensores();
    largadaFlag = false;
    fechouFlag  = false;

    estado = EST_CORRENDO;
    somBip(SOM_LARGADA_HZ, SOM_LARGADA_MS);
    if (ehDemo) Serial.println(F("[largada] corrida demo"));
    else        Serial.println(F("[largada]"));
}

static void registraChegada(uint8_t i, unsigned long t)
{
    if (pista[i].chegou) return;

    const unsigned long dt = t - t0Us;        /* subtracao sem sinal:
                                                 sobrevive ao estouro de
                                                 micros() aos 71 minutos   */
    if (dt > 3600000000UL) return;            /* chegou "antes" da largada */

    const uint32_t ms = (uint32_t)(dt / 1000UL);
    if (ms < TEMPO_MIN_MS) {
        /* Nenhum carrinho faz a pista nesse tempo: e repique do microswitch
           ou sujeira passando na barreira. */
        Serial.print(F("[ruido] pista "));
        Serial.print(i + 1);
        Serial.print(F(" disparou em "));
        Serial.print(ms);
        Serial.println(F(" ms, ignorado"));
        return;
    }

    pista[i].chegou  = true;
    pista[i].ms      = ms;
    pista[i].posicao = ++nChegadas;
    if (tPrimeiroUs == 0) tPrimeiroUs = t;

    dispPosicao(i, pista[i].posicao);
    somBip((uint16_t)(SOM_CHEGADA_HZ - 150 * pista[i].posicao), SOM_CHEGADA_MS);

    Serial.print(F("  "));
    Serial.print(pista[i].posicao);
    Serial.print(F("o lugar  pista "));
    Serial.print(i + 1);
    Serial.print(F("  "));
    serialTempo(ms);
    Serial.println();
}

static void mostraResultado(void)
{
    for (uint8_t i = 0; i < N_PISTAS; i++) {
        if (fase == FASE_POSICAO) {
            if (pista[i].chegou) dispPosicao(i, pista[i].posicao);
            else                 dispTexto(i, " dnF");
        } else {
            dispTempo(i, pista[i].chegou ? pista[i].ms : TEMPO_INVALIDO);
        }
    }
}

static void finaliza(void)
{
    estado       = EST_RESULTADO;
    fase         = FASE_POSICAO;
    tResultadoMs = millis();
    tFaseMs      = tResultadoMs;
    fechouFlag   = false;
    mostraResultado();
    somBip(SOM_FIM_HZ, SOM_FIM_MS);

    Serial.print(F("[fim] "));
    Serial.print(nChegadas);
    Serial.print(F(" de "));
    Serial.print(N_PISTAS);
    Serial.println(F(" chegaram"));

    for (uint8_t pos = 1; pos <= nChegadas; pos++)
        for (uint8_t i = 0; i < N_PISTAS; i++)
            if (pista[i].posicao == pos) {
                Serial.print(F("  "));
                Serial.print(pos);
                Serial.print(F("o  pista "));
                Serial.print(i + 1);
                Serial.print(F("  "));
                serialTempo(pista[i].ms);
                Serial.println();
            }
    for (uint8_t i = 0; i < N_PISTAS; i++)
        if (!pista[i].chegou) {
            Serial.print(F("  --  pista "));
            Serial.print(i + 1);
            Serial.println(F("  nao chegou"));
        }
}
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
void loop(void)
{
    trataBotao();
    switch (estado) {
    case EST_ARMADO:    tickArmado();    break;
    case EST_CORRENDO:  tickCorrendo();  break;
    case EST_RESULTADO: tickResultado(); break;
    }
    somTick();
    /*
     * A precisao do cronometro nao depende deste intervalo: quem carimba a
     * hora e a interrupcao, com micros(). O laco so decide e desenha.
     */
    delay(1);
}

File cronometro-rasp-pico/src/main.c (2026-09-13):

/* SPDX-License-Identifier: GPL-3.0-or-later */
/* Copyright (C) 2026 Leonardo Roman da Rosa */
/*
 * Cronometro de 6 pistas para pista de carrinhos Hot Wheels.
 *
 * Um microswitch na porta de largada marca o t0; um sensor de luz no fim
 * de cada pista marca a chegada; seis TM1637 mostram a colocacao e depois
 * o tempo. Alvo: RP2040 (Raspberry Pi Pico e clones).
 */
#include "pico/stdlib.h"
#include "cronometro.h"
#include "som.h"

#include <stdio.h>

int main(void)
{
    stdio_init_all();

    printf("\n=== cronometro-hotwheels ===\n");

    cronometro_init();

    while (true) {
        cronometro_tick();
        som_tick();
        /*
         * A precisao do cronometro nao depende deste intervalo: quem
         * carimba a hora e a interrupcao de GPIO, com time_us_64(). O loop
         * so decide e desenha.
         */
        sleep_ms(1);
    }
}

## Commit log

2026-09-13 cronometro: firmware RP2040 e Arduino, simuladores, fiacao e esquemas KiCad
    Cronometro de largada e chegada para pista Hot Wheels de 6 raias:
    microswitch na porta, sensor TCRT5000 por raia e seis displays TM1637
    mostrando colocacao e tempo.
    - cronometro-rasp-pico: firmware em C (Pico SDK 1.5.1) e simulador Wokwi
    - cronometro-arduino: o mesmo comportamento num sketch unico para UNO/Nano
    - tools/: geradores dos diagramas de fiacao (com conferencia automatica de
    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
    [cronometro-arduino.kicad_sch, cronometro-rasp-pico.kicad_sch]
2026-09-14 release: carimbo do KiCad, variantes do firmware e empacotador
    - esquemas: comentarios do carimbo encurtados, que estouravam a moldura da
    folha; o gerador agora recusa linha com mais de 62 caracteres
    - firmware: DISPLAY_PONTO_DECIMAL e SENSOR_NIVEL_CARRO sob #ifndef, com as
    opcoes -DPONTO_DECIMAL e -DSENSOR_NIVEL no CMake do Pico
    - tools/empacotar_release.py: um zip por placa, com LEIA-ME, binarios
    prontos, build/ para o simulador, fiacao em PNG e links fixados na tag
    - documentos do Arduino sem caminhos desta maquina; README, NOTAS e
    como-simular atualizados
    [cronometro-arduino.kicad_sch, cronometro-rasp-pico.kicad_sch]
